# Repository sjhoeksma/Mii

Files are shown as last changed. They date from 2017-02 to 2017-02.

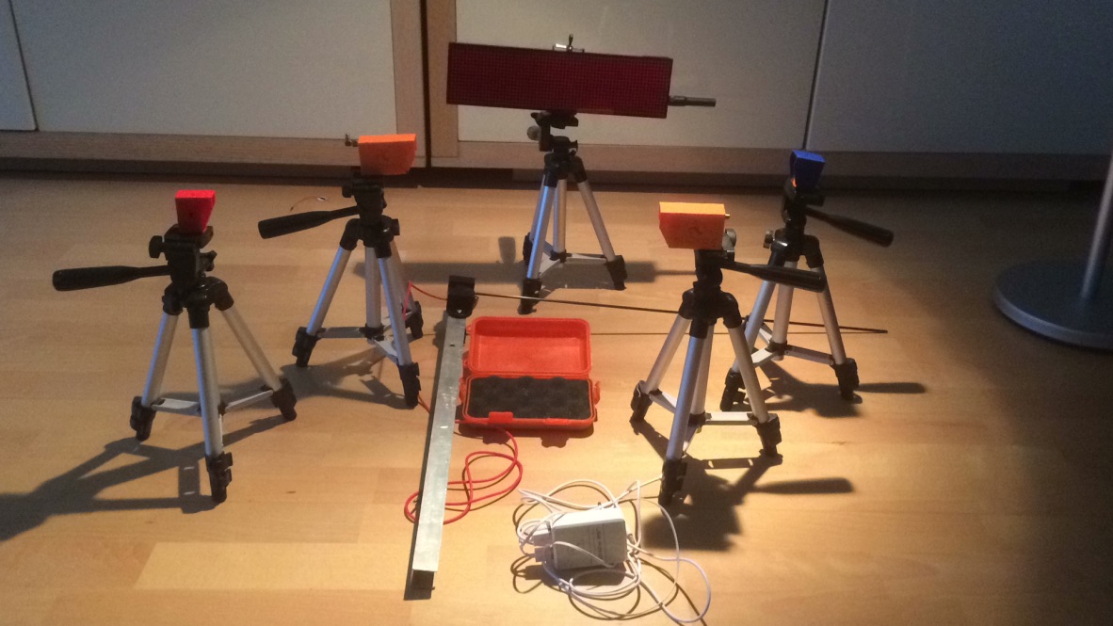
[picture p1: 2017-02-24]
img/overview.jpg

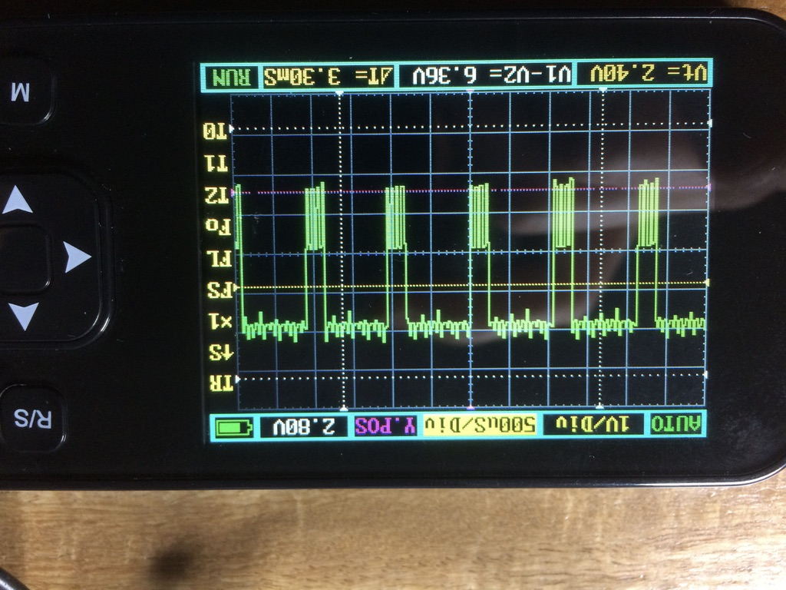
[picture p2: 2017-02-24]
img/pulsetrain.jpg

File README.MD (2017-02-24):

# Mii an Opensource Real Time, Timing solution
This solution can be used to create your own real time timing solution. It can be for example be used for mesuaring
the time needed to run a 10 meter sprint or do ski run.

We provide the hardware components, created with Eagle from CadSoft, emmbedded software written in arduino and a HTML5 app for Web & Mobile devices written with IONIC framework 1.3. For hardware components we provide the 3D models allowing you to print them your self.

## Components
1. MiiChrono and a MiiBeam make a start of finish line
2. MiiScoreboard can be used to show the time
3. MiiApp is the HMTL5 app
4. Mii3D are the 3D models for your printer in using openScad
5. Lib contains all libaries you need

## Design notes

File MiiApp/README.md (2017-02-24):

# 1. MiiApp Ionic Framework
Thanks for your interest in the **MiiApp Ionic Framework**. This framework will reduce the effort you require to build great hybrid applications.
We have combined the most common used native functions and with some great functions like dynamic load, so you can just focus on writting your code in HTML5.

## 1.1 Install Android Studio and XCode
Before you can build a native application your need to install Android Studio and XCode
1. Android: https://developer.android.com/studio/index.html
1. Apple: XCode from Appstore

## 1.2 Installing from scratch
1. Download nodejs from https://nodejs.org/en/download/ and install it
1. sudo npm install -g ionic
1. sudo npm install -g bower
1. sudo npm install -g cordova
1. sudo npm install -g gulp

Run cordova to complete the cordova installation

```
cordova
```

Install the following pacakges to install the IOS simulator on MacOS.

1. sudo npm install -g ios-sim
1. sudo npm install -g ios-deploy --unsafe-perm=true  --allow-root

## 1.3 Clone the repository
Make a clone of our repository with your GIT tool.

```
git clone https://github.com/sjhoeksma/dwp-ss.git
cd dwp-ss
```

## 1.4 Download all required packages
1. npm install
1. bower install
1. ionic state reset
1. ionic resources

## 1.5 Additional Platforms
By default we install IOS and Android would you like to add another platform just list type **ionc platform ls** and then add type **ionic platform add XXX**
 
# 2. Start your development
You have now successfully installed Ionic and our framework. You will need to configure it. Open the file [www/js/config.js](https://github.com/sjhoeksma/dwp-ss/blob/master/www/js/config.js) and set your preferences.
We support different kind of secuirty elements enabling you to make enterprise grade applications. By default all security and backend services are **disabled**.

## 2.1 Understanding the architecture

### Evergreen process of modules (remote sync)
We use a evergreen process to keep your mobile application updated to latest version. This will require you to deploy the framework towards a webserver. During the build process we create a **modules.json** file containing all available modules and there version number. For all modules you have installed we will check if there is a never version available on the webserver and then download and install it. Next time you application goes to the home state **app.home** the application will reload and you have the latest version of all modules.

## 2.2 Create your first Module

## 2.3 Build or Test your first Module
Now you have you created your module you want to test it. You should first test your app in the browser by using the following command from the root directory of your project.

```
ionic serve -c -l
```
This will start up your browser and the live reload services and dumps all message of the console.

If you are happy with you code you can build a real version and test it in an emulator like this

```
ionic emulate ios -c -l
or
ionic emulate android -c -l
```
This will start the emulator of your choice, in live reload. If you want to have a real package remove *-c -l*. 

**Warning: On android no cordova plugins are loaded when using live reload**

When you are finally happy with your result you can run in on a real device by using.

```
ionic run
```
or even build the real version

```
ionic build --production
or
ionic build [--development]
```
The prodcution build will create a compressed version of the code, without debug infomation. Therefor you should not use it for testing purposes. Development is the default behaivour. You will need to sign your app before you can deploy them to a appstore or any apple device.

## 2.4 Setup signing of application
### Android

### Apple

## 2.5 Developer documentation
The framework comes with a number of states, which you may want to overwrite of use
* **app.home** The default home screen contains a single app or a grid of apps when more installed
* **app.settings** Screen where use can changes general settings (language,theme) or module specific
* **app.store** A store where a user can add or remove a module
* **app.notifications** A webpage showing all notifications
* **app.about** Text about your app (basic info in language files)
* **app.firsttime** Text show when user starts application for fist time (basic info in language files)
* **app.whatsnew** Text shown when a new version of the application is started after download from app store (basic info in language files)

#### Pages normally not modified (except language files)
* **app.login** The login page.
* **app.logout** This state will redirect automactily back to the app.login state
* **app.webpage** Opens the webpage in iframe of in appbrowser depending on the config you specified
* **app.privacy** This page shows general information about how you should use this app if you want to protect you privacy as a end user
* **app.opensource** This page shows the opensource license and all links to the packages we have used.

* **app.newpin** This is a model view page which is shown in case an user needs to set a pin. This function can be used by enterprise who use a claim based authorization model and want to lock the user after x minutues of in activity, but don't require the user to retreive a new claim. When a pin code is set we will use this pincode to encrypt data in the app.

All the Factories,Providers and Services within the framework are document using ngDoc. We do our best to make usable documentation, but please help us making it exellent.

**Directives**
* [IonKeyPad]()
* [MenuTree]()
* [GridMenu]()

**Providers**
* [SecureStorage]()
* [LoadOnDemand]()
* [SyncQueue]()
* [FilePicker]()

**Services**
* [AppUser]()
* [IdelStateTimer]()
* [NetworkMonitor]()
* [Notifications]()

# 3. Technical information
This section explains the installation process of all packages used by the framework. You don't need to do this is you have followed the instructions at the beginning of this document

## 3.1 Codova plugins packages
Cordova plugins are automaticly to packages.json and therefor reloaded during the state reset command of ionic. If for some reason this did not happend you can add the packages yourself.
* ionic plugin add cordova-plugin-whitelist  --save
* ionic plugin add cordova-plugin-appavailability --save
* ionic plugin add cordova-plugin-camera --save
* ionic plugin add cordova-plugin-network-information --save
* ionic plugin add cordova-plugin-file --save
* ionic plugin add cordova-plugin-powermanagement --save
* ionic plugin add cordova-plugin-vibration --save
* ionic plugin add cordova-plugin-app-version --save
* ionic plugin add cordova-plugin-keychain-touch-id --save
* ionic plugin add cordova-plugin-crosswalk-webview@1.7 --save
* ionic plugin add cordova-plugin-nativeclicksound --save
* ionic plugin add cordova-plugin-badge --save
* ionic plugin add cordova-plugin-ms-adal --save
* ionic plugin add cordova-plugin-themeablebrowser --save 
* ionic plugin add phonegap-plugin-push --variable SENDER_ID=123232 --save
* ionic plugin add phonegap-plugin-contentsync --save
* ionic plugin add cordova-custom-config --save
* ionic plugin add cordova-plugin-file-transfer --save
* ionic plugin add http://github.com/don/cordova-filechooser.git --save
* ionic plugin add cordova-plugin-backbutton --save
* ionic plugin add cordova-plugin-bluetooth-serial --save

## 3.2 Javascript libraries
JavaScript libraries are also automaticly added during the ionic state reset command because they where added to bower.json.
* bower install --save angular-translate
* bower install --save angular-translate-loader-static-files
* bower install --save angular-translate-loader-partial
* bower install --save angular-cookies
* bower install --save crypto-js
* bower install --save ngCordova
* bower install --save ion-datetime-picker
* bower install --save jquery 
* bower install --save nz-tour
* bower install --save crypto-js
* bower install --save idle.js
* bower install --save Leaflet
* bower install --save adal-angular
* bower install --save https://github.com/sjhoeksma/ionic-gizmos.git
* bower install --save https://github.com/sjhoeksma/nzTour.git
* bower install --save ionic-select-control
* bower install --save localforage 
* bower install --save angular-localforage
* bower install --save https://github.com/localForage/localForage-sessionStorageWrapper.git
* bower install --save angular-formly
* bower install --save owl.carousel
* bower install --save pdfmake

## 3.3 Setting up testing with karma 
Based on the following links: [link1](http://mcgivery.com/unit-testing-ionic-app) and [link2](http://gonehybrid.com/how-to-write-automated-tests-for-your-ionic-app-part-2/) we have created some unit test. To run a test you can use the command **gulp test** from the command line.

```
npm install karma karma-jasmine jasmine-core karma-phantomjs-launcher karma-html-reporter karma-chrome-launcher karma-mocha-reporter karma-ng-html2js-preprocessor karma-html-reporter --save
bower install angular-mocks#1.5.x --save
sudo npm install -g karma-cli
sudo npm install -g phantomjs
mkdir -p tests/unit-tests
cd tests
karma init unit-tests.conf.js
```

## 3.4 Known Issues
1. When login you can be prompted to validate adfs again we trigger autheticate while user entered Valid Pin
2.

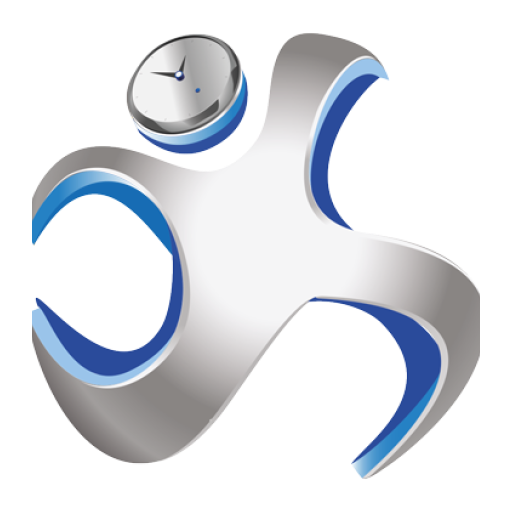
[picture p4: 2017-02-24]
MiiApp/www/modules/app.miichrono/miichrono.png

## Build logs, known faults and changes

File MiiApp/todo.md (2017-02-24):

BaasBox.com als vervanging van Backendless.com
Disable ADAL by option
+Disable login option
+Single App loaded start app directly
Secure storage without encryption
Secure storage with WebCrypto
+Secure storage remove native option
Remove bug, hardware back button on forget's go's to home
Looks like loading of scripts not yet correct. MiiChrono does not work without outloading
+Show time clock in App
+Set time of phone when time is not set
+Divider when using ranking by group
+Selection of time should be better
+Save the settings
copy user by cloning from other session
firmware sometimes empty resend request
style sheet blue is keyboard transparent
+ranking does not work with without gender (looks like we need two before it works)
+reopen time does not work, should be not visable when not connected, and only if within last received block
+focusme in ionicpopup
+add session werkt niet
+dnf can be reopend
+no differance in ranking / no group
+tijd clock in local time
send result to bluetooth printer
does auto reconnect while use bluetooth is disabeld
+Strange behavoiur on ionicpopup firstime data is not connected	
+use bleutooth of seems to block outgoing commands ?
App create pdf with report and share (https://github.com/EddyVerbruggen/SocialSharing-PhoneGap-Plugin)
Full screen for time
+Follow user list
Remove item from middle of list goes wrong
+Have option to view list bast on start nr / Seq Nr
Have option to add seqnr to user,more data like points
Have a option to sort start list base on points
upload user and data
+When deleteing 3 items ranking was off
+Change user to time in popover
+check how data/time is set, should delta be removed
+have option to add next on start to app
Just log switches, so we can set time manual
+System goes in parrallel mode ? --> Locks like display issue (increase keyboard val with 5 and moved code down)
+No difference shown for empty groups/gender
+on disconnect clear all active times
full screen on rotate of device (landscape)
+Blink red on master when no devices connected
+Support parrallel mode
+Finish van nieuwe set blijft rebooten, --> Pin SW2 van audoplug op board stond open
+reset should also send reset to device when connected
+Paralel op display geef rare text L?, moet L+ zijn
Display is reseting,  check if condensator is 47uf (done)
Pallel mode what to display what in APP, (show only finish list, with no diff and no rank)
Option to keep keyboard to enter seqeunce always on (Snele invoer van volgende start nr)
Add config option to app forcing ping code top be set active, or general option
Move apitoken and login to service to app, allow for sharing the same login 

Replace the $http function with option to use a state config, therefore we should add state to queue

3D printing
Create a click for the start gate war stokje in past
Gate met externe spring veer

Lint the javascripts

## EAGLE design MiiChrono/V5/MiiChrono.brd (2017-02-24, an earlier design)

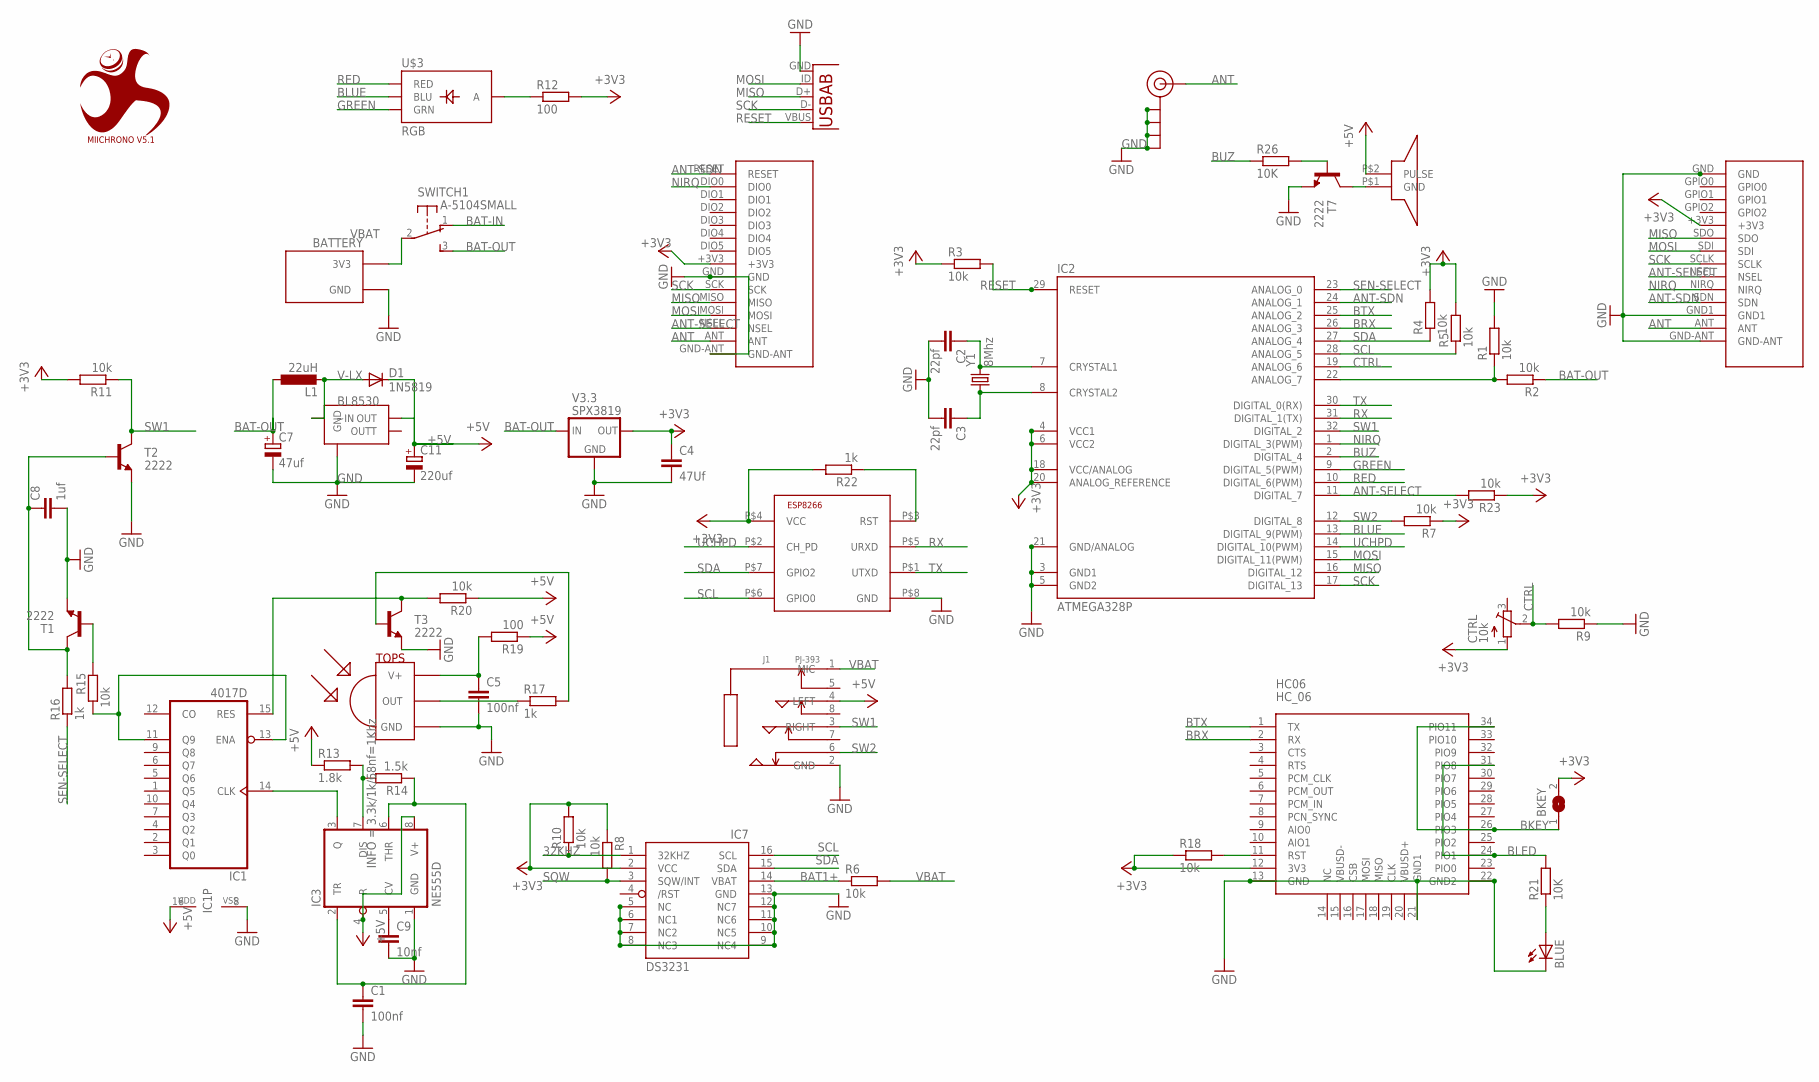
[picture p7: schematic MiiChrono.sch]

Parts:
BATTERY: GOPRO3BATTERY
BKEY: SOLDERJUMPER; SOLDERJUMPER_ARROW_NOPASTE
BL8530: BL8530; SOT89
BLUE: LEDCHIP-LED0805; CHIP-LED0805
BUZZER: BUZZER
C1, C5: 100nf; C0805
C2, C3: 22pf; C0805
C4: 47Uf; C0805
C7: 47uf; SMC_A
C8: 1uf; C0805
C9: 10nf; C0805
C11: 220uf; CT3528
CTRL: 10k; TC33X
D1: 1N5819; DO214AC
HC06: HC_06; BLUETOOTH_SMD
IC1: 4017D; SO16
IC2: ATMEGA328P; TQFP32-08
IC3: NE555D; SO08
IC7: DS3231/SO; SO16W
ISP1: USB-ABUSB_SIERK; USB_AB_MICRO_SJH
J1: PJ-393; AUDIO8P-SMD-3.5-14.5X6.1X4.0MM
J$1: SMA_EDGE; SMA-EDGE
L1: 22uH; L1812
R1, R2, R3, R4, R5, R6, R7, R8, R9, R10, R11, R15, R18, R20, R23: 10k; R0805
R12, R19: 100; R0805
R13: 1.8k; R0805
R14: 1.5k; R0805
R16, R17, R22: 1k; R0805
R21, R26: 10K; R0805
SWITCH: A-5104SMALL; A-5104-SMALL
T1, T2, T3, T7: 2222; SOT23
TOPS: TSOP4838; TSOP18XX
U$1: MIICHRONO V5.1; MIICHRONO
U$2: DRF1278F
U$3: RGB; LED-TRICOLOR-SMD
U$4: ESP8266-01; ESP-01
U$7: SI4432
V3.3: SPX3819; SOT23-5
Y1: 8Mhz; HC49UP

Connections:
32KHZ: IC7.1 (32KHZ), R10.1
+3V3: BKEY.2, C4.1, CTRL.1 (A), HC06.12 (3V3), IC2.4 (VCC1), IC2.6 (VCC2), IC2.18 (VCC/ANALOG), IC2.20 (ANALOG_REFERENCE), IC7.2 (VCC), R3.1, R4.2, R5.2, R7.1, R8.1, R10.2, R11.2, R12.2, R18.1, R22.2, R23.1, U$2.+3V3, U$4.P$4 (VCC), U$7.+3V3, V3.3.5 (OUT)
+5V: BL8530.2 (OUT), BUZZER.P$2 (PULSE), C11.+, D1.C, IC1.16 (VDD), IC3.4 (R), IC3.8 (V+), J1.4 (LEFT), R13.1, R19.1, R20.1
ANT: J$1.$P1 (SIGNAL), U$2.ANT, U$7.ANT
ANT-SDN: IC2.24 (ANALOG_1), U$2.RESET, U$7.SDN
ANT-SELECT: IC2.11 (DIGITAL_7), R23.2, U$2.NSEL, U$7.NSEL
BAT1+: IC7.14 (VBAT), R6.1
BAT-IN: SWITCH.1 (O)
BAT-OUT: C7.+, L1.1, R2.1, SWITCH.3 (S), V3.3.1 (IN), V3.3.3 (IN)
BKEY: BKEY.1, HC06.26 (PIO3), HC06.34 (PIO11)
BLED: HC06.24 (PIO1), HC06.31 (PIO8), R21.2
BLUE: IC2.13 (DIGITAL_9(PWM)), U$3.B (BLU)
BRX: HC06.2 (RX), IC2.26 (ANALOG_3)
BTX: HC06.1 (TX), IC2.25 (ANALOG_2)
BUZ: IC2.2 (DIGITAL_4), R26.1
CTRL: CTRL.2 (S), IC2.19 (ANALOG_6), R9.2
GND: BATTERY.GND, BL8530.1 (GND), BLUE.C, C1.2, C2.2, C3.2, C4.2, C5.2, C7.-, C8.2, C9.2, C11.-, HC06.13 (GND), HC06.21 (GND1), HC06.22 (GND2), IC1.8 (VSS), IC2.3 (GND1), IC2.5 (GND2), IC2.21 (GND/ANALOG), IC3.1 (GND), IC7.5 (NC), IC7.6 (NC1), IC7.7 (NC2), IC7.8 (NC3), IC7.9 (NC4), IC7.10 (NC5), IC7.11 (NC6), IC7.12 (NC7), IC7.13 (GND), ISP1.GND, J1.2 (GND), J$1.GND@0 (GND), J$1.GND@1 (GND), J$1.GND@2 (GND), J$1.GND@3 (GND), R1.2, R9.1, T1.2 (E), T2.2 (E), T3.2 (E), T7.2 (E), TOPS.GND, U$2.GND, U$2.GND-ANT, U$4.P$8 (GND), U$7.GND, U$7.GND1, U$7.GND-ANT, V3.3.2 (GND)
GREEN: IC2.9 (DIGITAL_5(PWM)), U$3.G (GRN)
MISO: IC2.16 (DIGITAL_12), ISP1.D+, U$2.MISO, U$7.SDO
MOSI: IC2.15 (DIGITAL_11(PWM)), ISP1.ID (USBID), U$2.MOSI, U$7.SDI
unnamed: R17.2, T3.1 (B)
unnamed: C9.1, IC3.5 (CV)
unnamed: HC06.11 (RST), R18.2
unnamed: C8.1, R16.2, T1.3 (C), T2.1 (B)
unnamed: IC1.11 (Q9), IC1.13 (ENA), R15.1
unnamed: R22.1, U$4.P$3 (RST)
unnamed: C3.1, IC2.8 (CRYSTAL2), Y1.1
unnamed: C2.1, IC2.7 (CRYSTAL1), Y1.2
unnamed: R15.2, T1.1 (B)
unnamed: R12.1, U$3.A
unnamed: C1.1, IC3.2 (TR), IC3.6 (THR), R14.1
unnamed: BLUE.A, R21.1
unnamed: IC1.14 (CLK), IC3.3 (Q)
unnamed: IC3.7 (DIS), R13.2, R14.2
unnamed: R17.1, TOPS.OUT
unnamed: C5.1, R19.2, TOPS.VCC (V+)
unnamed: IC1.15 (RES), R20.2, T3.3 (C)
unnamed: IC2.22 (ANALOG_7), R1.1, R2.2
unnamed: R26.2, T7.1 (B)
unnamed: BUZZER.P$1 (GND), T7.3 (C)
NIRQ: IC2.1 (DIGITAL_3(PWM)), U$2.DIO0, U$7.NIRQ
RED: IC2.10 (DIGITAL_6(PWM)), U$3.R (RED)
RESET: IC2.29 (RESET), ISP1.VBUS, R3.2
RX: IC2.31 (DIGITAL_1(TX)), U$4.P$5 (URXD)
SCK: IC2.17 (DIGITAL_13), ISP1.D-, U$2.SCK, U$7.SCLK
SCL: IC2.28 (ANALOG_5), IC7.16 (SCL), R5.1, U$4.P$6 (GPIO0)
SDA: IC2.27 (ANALOG_4), IC7.15 (SDA), R4.1, U$4.P$7 (GPIO2)
SEN-SELECT: IC2.23 (ANALOG_0), R16.1
SQW: IC7.3 (SQW/INT), R8.2
SW1: IC2.32 (DIGITAL_2), J1.3 (RIGHT), R11.1, T2.3 (C)
SW2: IC2.12 (DIGITAL_8), J1.6, R7.2
TX: IC2.30 (DIGITAL_0(RX)), U$4.P$1 (UTXD)
UCHPD: IC2.14 (DIGITAL_10(PWM)), U$4.P$2 (CH_PD)
V-LX: BL8530.3 (~IN), D1.A, L1.2
VBAT: BATTERY.3V3, J1.1 (MIC), R6.2, SWITCH.2

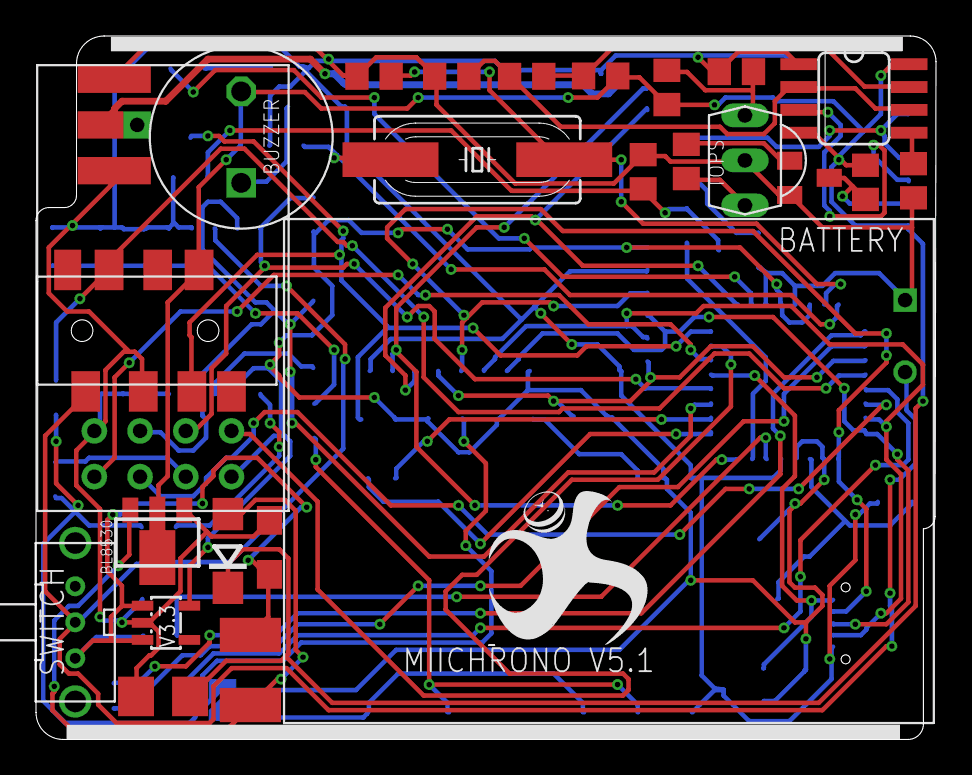
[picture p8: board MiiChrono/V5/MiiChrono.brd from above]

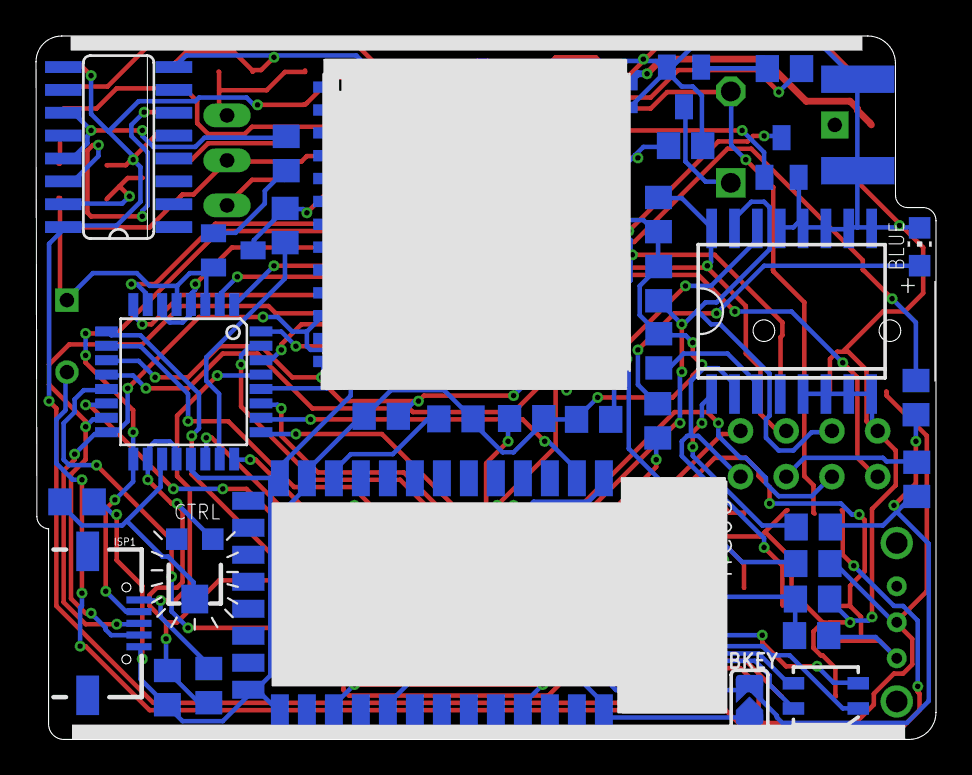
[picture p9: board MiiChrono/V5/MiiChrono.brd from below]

Board: 2 copper layers, 50.0 x 39.1 mm, 62 parts (35 on the bottom side), 54 nets.

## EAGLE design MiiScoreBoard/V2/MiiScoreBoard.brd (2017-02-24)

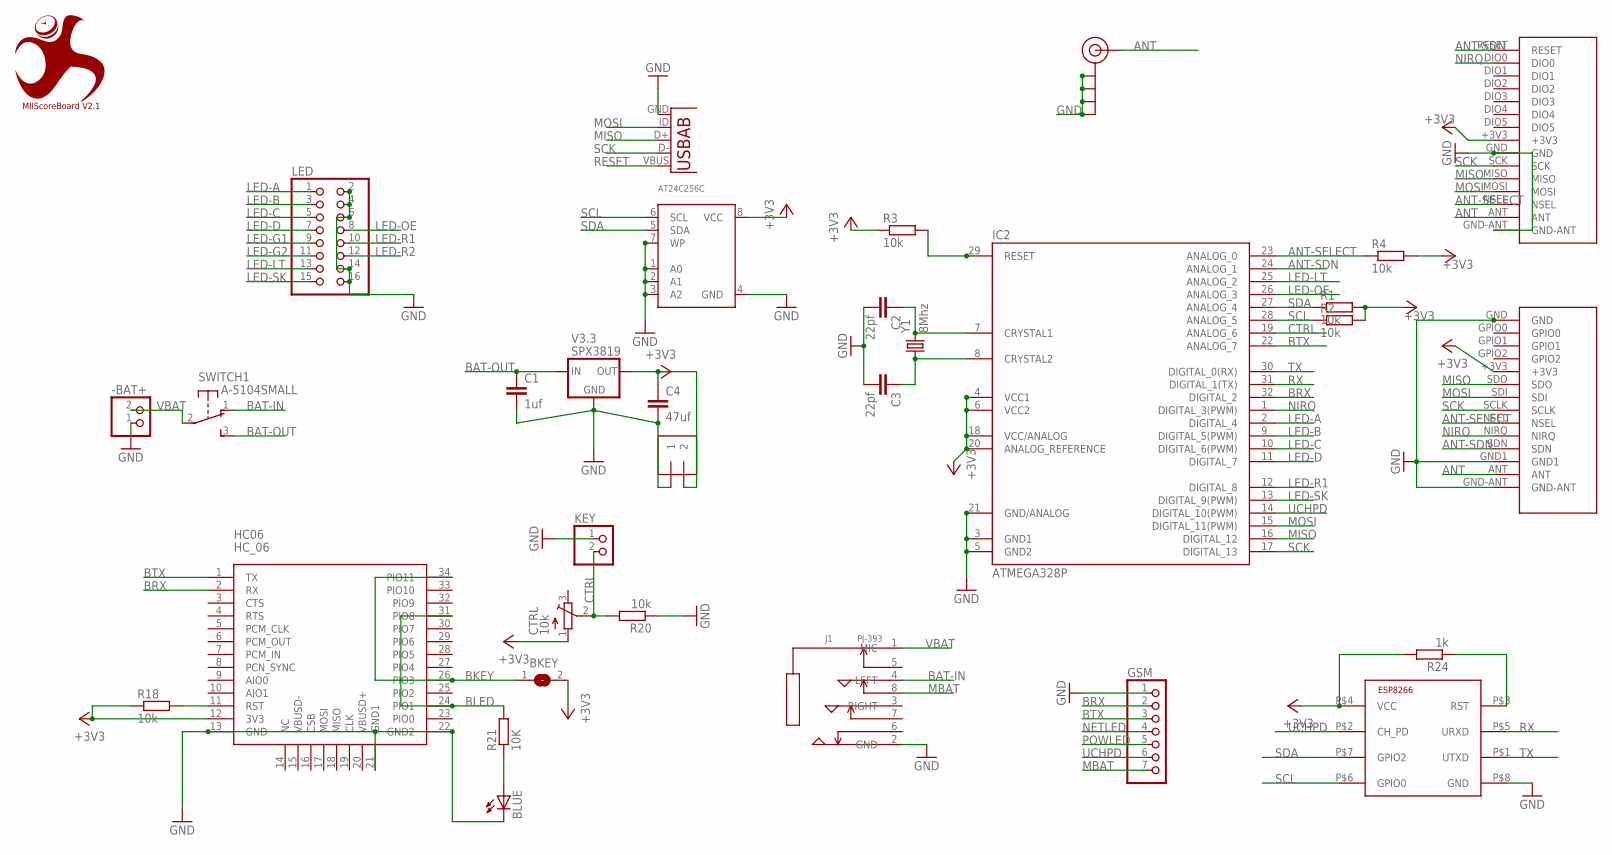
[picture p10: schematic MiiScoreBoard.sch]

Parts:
-BAT+: JST_2PIN-THM; JST-PH-2-THM
-LED+: -BAT+; 1X2-3.5MM
AT24C256C: EEPROM_I2C_SOIC8_GENERIC; SOIC8_150MIL
BKEY: SOLDERJUMPER; SOLDERJUMPER_ARROW_NOPASTE
BLUE: LEDCHIP-LED0805; CHIP-LED0805
C1: 1uf; C0805
C2, C3: 22pf; C0805
C4: 47uf; C0805
CTRL: 10k; TC33X
GSM: PINHD-1X07_2.54; 1X07
HC06: HC_06; BLUETOOTH_SMD
IC2: ATMEGA328P; TQFP32-08
ISP1: USB-ABUSB_SIERK; USB_AB_MICRO_SJH
J1: PJ-393; AUDIO8P-SMD-3.5-14.5X6.1X4.0MM
J$1: SMA_EDGE; SMA-EDGE
KEY: PINHD-1X02_2.54-90°; 1X02/90
LED: PINHD-2X08_2.54; 2X08
R1, R2, R3, R4, R18, R20: 10k; R0805
R21: 10K; R0805
R24: 1k; R0805
SWITCH: A-5104SMALL; A-5104-SMALL
U$1: MIIScoreBoard V2.1; MIICHRONO
U$2: DRF1278F
U$6: ESP8266-01; ESP-01
U$7: SI4432
V3.3: SPX3819; SOT23-5
Y1: 8Mhz; HC49UP

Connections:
+3V3: -LED+.2, AT24C256C.8 (VCC), BKEY.2, C4.1, CTRL.1 (A), HC06.12 (3V3), IC2.4 (VCC1), IC2.6 (VCC2), IC2.18 (VCC/ANALOG), IC2.20 (ANALOG_REFERENCE), R1.2, R2.2, R3.1, R4.2, R18.1, R24.2, U$2.+3V3, U$6.P$4 (VCC), U$7.+3V3, V3.3.5 (OUT)
ANT: J$1.$P1 (SIGNAL), U$2.ANT, U$7.ANT
ANT-SDN: IC2.24 (ANALOG_1), U$2.RESET, U$7.SDN
ANT-SELECT: IC2.23 (ANALOG_0), R4.1, U$2.NSEL, U$7.NSEL
BAT-IN: J1.4 (LEFT), SWITCH.1 (O)
BAT-OUT: C1.1, SWITCH.3 (S), V3.3.1 (IN), V3.3.3 (IN)
BKEY: BKEY.1, HC06.26 (PIO3), HC06.34 (PIO11)
BLED: HC06.24 (PIO1), HC06.31 (PIO8), R21.2
BRX: GSM.2, HC06.2 (RX), IC2.32 (DIGITAL_2)
BTX: GSM.3, HC06.1 (TX), IC2.22 (ANALOG_7)
CTRL: CTRL.2 (S), IC2.19 (ANALOG_6), KEY.2, R20.2
GND: -BAT+.1 (2), -LED+.1, AT24C256C.1 (A0), AT24C256C.2 (A1), AT24C256C.3 (A2), AT24C256C.4 (GND), AT24C256C.7 (WP), BLUE.C, C1.2, C2.2, C3.2, C4.2, GSM.1, HC06.13 (GND), HC06.21 (GND1), HC06.22 (GND2), IC2.3 (GND1), IC2.5 (GND2), IC2.21 (GND/ANALOG), ISP1.GND, J1.2 (GND), J$1.GND@0 (GND), J$1.GND@1 (GND), J$1.GND@2 (GND), J$1.GND@3 (GND), KEY.1, LED.2, LED.4, LED.6, LED.14, LED.16, R20.1, U$2.GND, U$2.GND-ANT, U$6.P$8 (GND), U$7.GND, U$7.GND1, U$7.GND-ANT, V3.3.2 (GND)
LED-A: IC2.2 (DIGITAL_4), LED.1
LED-B: IC2.9 (DIGITAL_5(PWM)), LED.3
LED-C: IC2.10 (DIGITAL_6(PWM)), LED.5
LED-D: IC2.11 (DIGITAL_7), LED.7
LED-G1: LED.9
LED-G2: LED.11
LED-LT: IC2.25 (ANALOG_2), LED.13
LED-OE: IC2.26 (ANALOG_3), LED.8
LED-R1: IC2.12 (DIGITAL_8), LED.10
LED-R2: LED.12
LED-SK: IC2.13 (DIGITAL_9(PWM)), LED.15
MBAT: GSM.7, J1.8
MISO: IC2.16 (DIGITAL_12), ISP1.D+, U$2.MISO, U$7.SDO
MOSI: IC2.15 (DIGITAL_11(PWM)), ISP1.ID (USBID), U$2.MOSI, U$7.SDI
unnamed: HC06.11 (RST), R18.2
unnamed: C3.1, IC2.8 (CRYSTAL2), Y1.1
unnamed: C2.1, IC2.7 (CRYSTAL1), Y1.2
unnamed: R24.1, U$6.P$3 (RST)
unnamed: BLUE.A, R21.1
NETLED: GSM.4
NIRQ: IC2.1 (DIGITAL_3(PWM)), U$2.DIO0, U$7.NIRQ
POWLED: GSM.5
RESET: IC2.29 (RESET), ISP1.VBUS, R3.2
RX: IC2.31 (DIGITAL_1(TX)), U$6.P$5 (URXD)
SCK: IC2.17 (DIGITAL_13), ISP1.D-, U$2.SCK, U$7.SCLK
SCL: AT24C256C.6 (SCL), IC2.28 (ANALOG_5), R2.1, U$6.P$6 (GPIO0)
SDA: AT24C256C.5 (SDA), IC2.27 (ANALOG_4), R1.1, U$6.P$7 (GPIO2)
TX: IC2.30 (DIGITAL_0(RX)), U$6.P$1 (UTXD)
UCHPD: GSM.6, IC2.14 (DIGITAL_10(PWM)), U$6.P$2 (CH_PD)
VBAT: -BAT+.2 (1), J1.1 (MIC), SWITCH.2

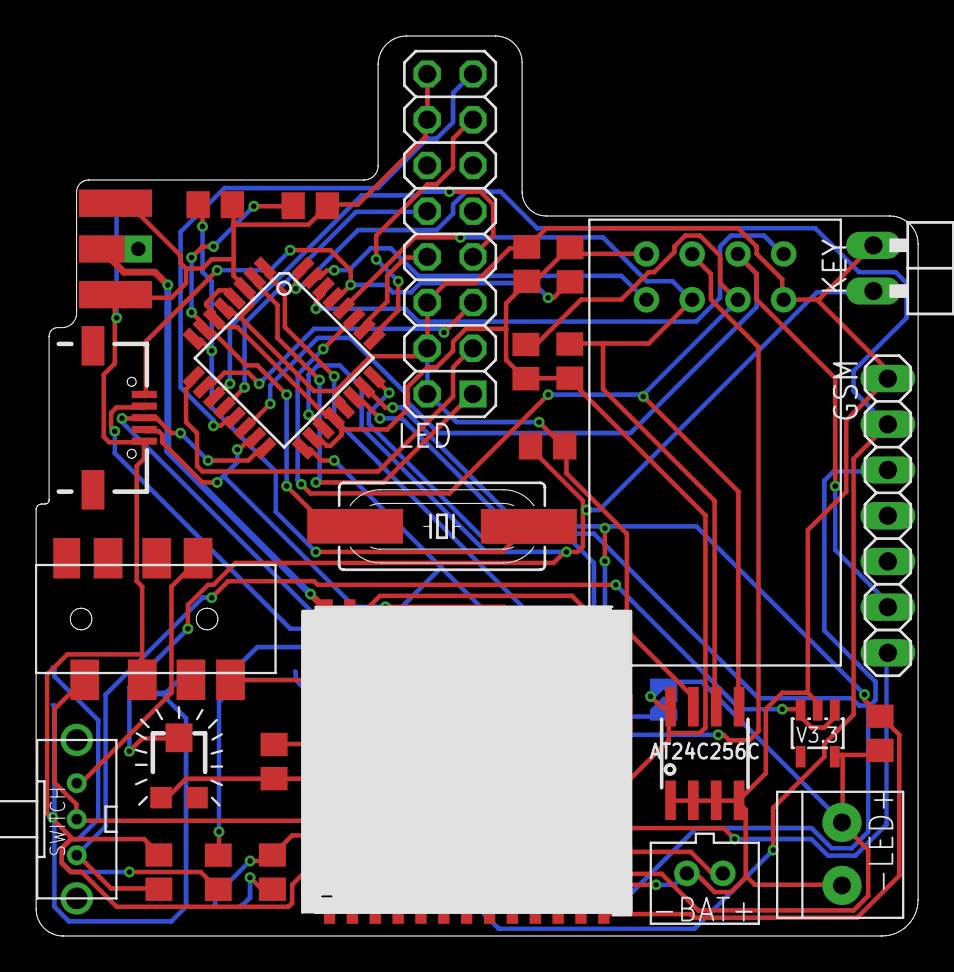
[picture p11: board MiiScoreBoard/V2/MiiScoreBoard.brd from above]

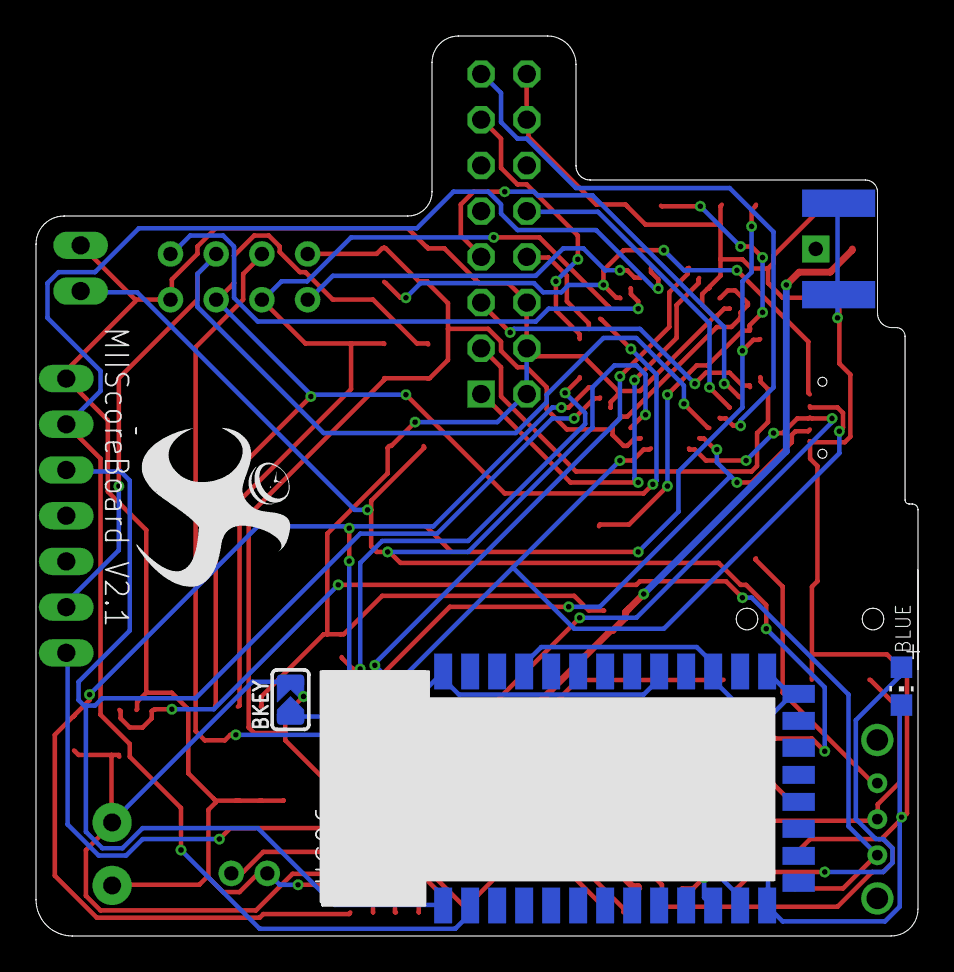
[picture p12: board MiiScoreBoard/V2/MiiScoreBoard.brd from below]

Board: 2 copper layers, 49.0 x 50.0 mm, 33 parts (4 on the bottom side), 37 nets.

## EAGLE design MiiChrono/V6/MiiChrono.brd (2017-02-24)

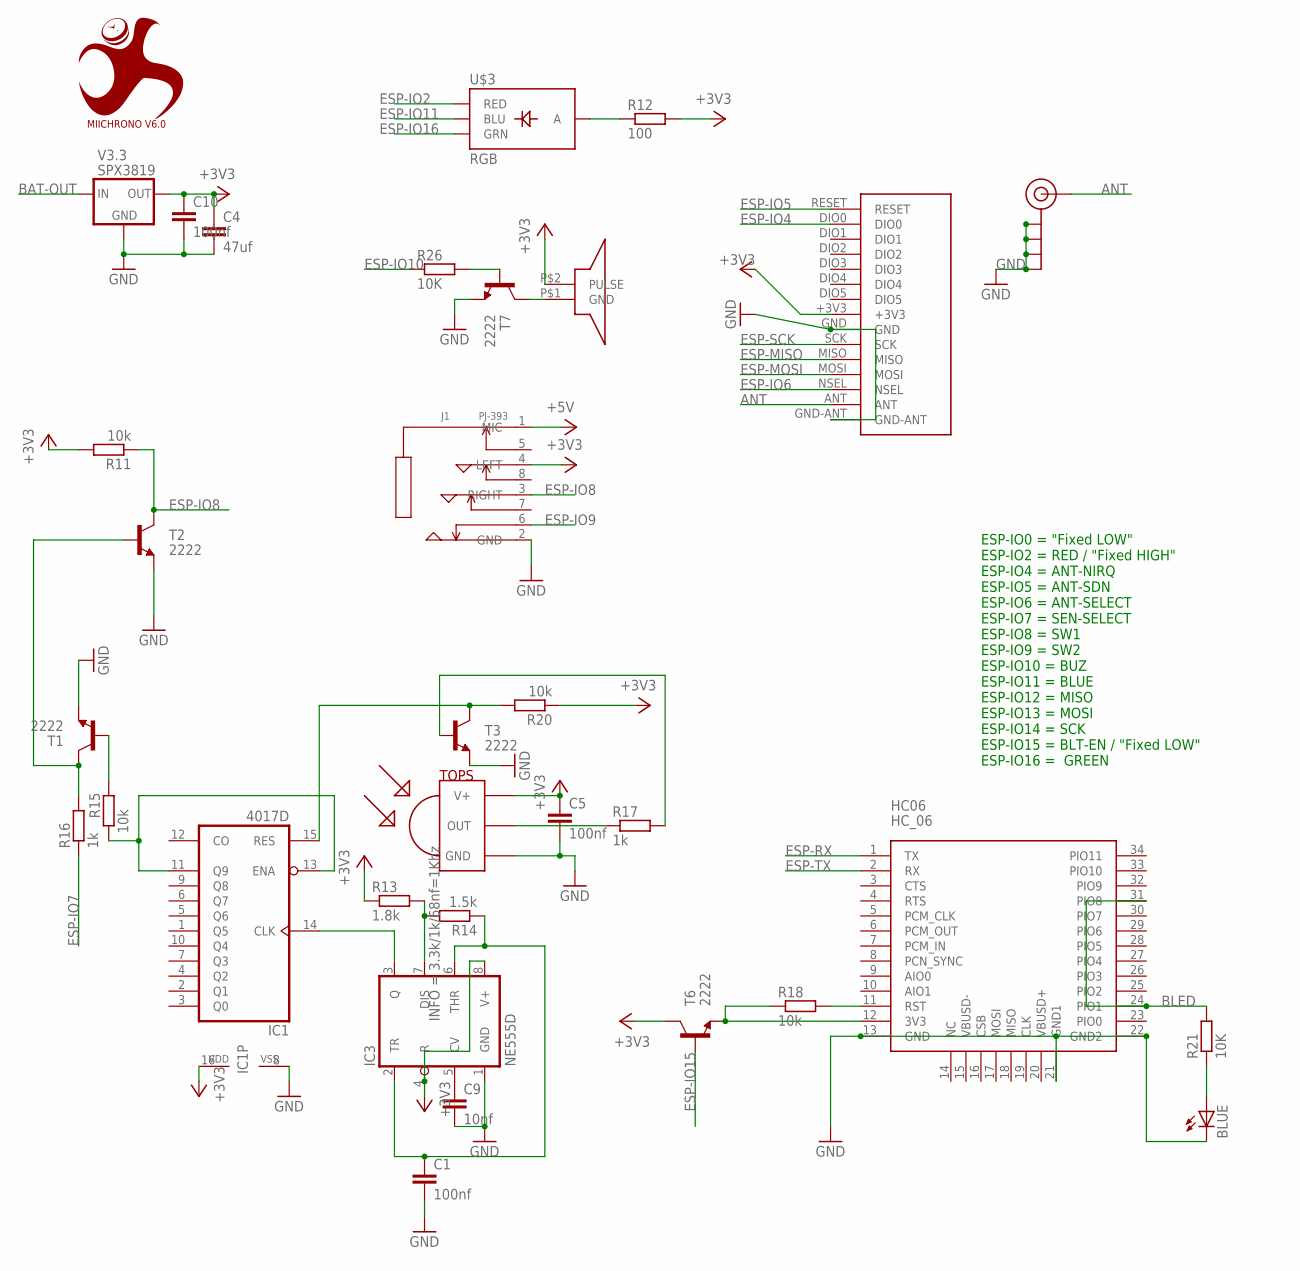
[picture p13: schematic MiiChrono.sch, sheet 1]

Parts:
BLUE: LEDCHIP-LED0805; CHIP-LED0805
BUZZER: BUZZER
C1, C5, C10: 100nf; C0805
C4: 47uf; C0805
C9: 10nf; C0805
HC06: HC_06; BLUETOOTH_SMD
IC1: 4017D; SO16
IC3: NE555D; SO08
J1: PJ-393; AUDIO8P-SMD-3.5-14.5X6.1X4.0MM
J$1: SMA_EDGE; SMA-EDGE
R11, R15, R18, R20: 10k; R0805
R12: 100; R0805
R13: 1.8k; R0805
R14: 1.5k; R0805
R16, R17: 1k; R0805
R21, R26: 10K; R0805
T1, T2, T3, T6, T7: 2222; SOT23
TOPS: TSOP4838; TSOP18XX
U$1: MIICHRONO V6.0; MIICHRONO
U$2: DRF1278F
U$3: RGB; LED-TRICOLOR-SMD
V3.3: SPX3819; SOT23-5

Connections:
+3V3: BUZZER.P$2 (PULSE), C4.1, C5.1, C10.1, IC1.16 (VDD), IC3.4 (R), IC3.8 (V+), J1.4 (LEFT), R11.2, R12.2, R13.1, R20.1, T6.3 (C), TOPS.VCC (V+), U$2.+3V3, V3.3.5 (OUT)
+5V: J1.1 (MIC); also elsewhere on the board
ANT: J$1.$P1 (SIGNAL), U$2.ANT
BAT-OUT: V3.3.1 (IN), V3.3.3 (IN); also elsewhere on the board
BLED: HC06.24 (PIO1), HC06.31 (PIO8), R21.2
ESP-IO2: U$3.R (RED); also elsewhere on the board
ESP-IO4: U$2.DIO0; also elsewhere on the board
ESP-IO5: U$2.RESET; also elsewhere on the board
ESP-IO6: U$2.NSEL; also elsewhere on the board
ESP-IO7: R16.1; also elsewhere on the board
ESP-IO8: J1.3 (RIGHT), R11.1, T2.3 (C); also elsewhere on the board
ESP-IO9: J1.6; also elsewhere on the board
ESP-IO10: R26.1; also elsewhere on the board
ESP-IO11: U$3.B (BLU); also elsewhere on the board
ESP-IO15: T6.1 (B); also elsewhere on the board
ESP-IO16: U$3.G (GRN); also elsewhere on the board
ESP-MISO: U$2.MISO; also elsewhere on the board
ESP-MOSI: U$2.MOSI; also elsewhere on the board
ESP-RX: HC06.1 (TX); also elsewhere on the board
ESP-SCK: U$2.SCK; also elsewhere on the board
ESP-TX: HC06.2 (RX); also elsewhere on the board
GND: BLUE.C, C1.2, C4.2, C5.2, C9.2, C10.2, HC06.13 (GND), HC06.21 (GND1), HC06.22 (GND2), IC1.8 (VSS), IC3.1 (GND), J1.2 (GND), J$1.GND@0 (GND), J$1.GND@1 (GND), J$1.GND@2 (GND), J$1.GND@3 (GND), T1.2 (E), T2.2 (E), T3.2 (E), T7.2 (E), TOPS.GND, U$2.GND, U$2.GND-ANT, V3.3.2 (GND); also elsewhere on the board
unnamed: R17.2, T3.1 (B)
unnamed: C9.1, IC3.5 (CV)
unnamed: R16.2, T1.3 (C), T2.1 (B)
unnamed: IC1.11 (Q9), IC1.13 (ENA), R15.1
unnamed: HC06.12 (3V3), R18.1, T6.2 (E)
unnamed: R15.2, T1.1 (B)
unnamed: R12.1, U$3.A
unnamed: C1.1, IC3.2 (TR), IC3.6 (THR), R14.1
unnamed: HC06.11 (RST), R18.2
unnamed: IC1.14 (CLK), IC3.3 (Q)
unnamed: IC3.7 (DIS), R13.2, R14.2
unnamed: R17.1, TOPS.OUT
unnamed: BLUE.A, R21.1
unnamed: IC1.15 (RES), R20.2, T3.3 (C)
unnamed: R26.2, T7.1 (B)
unnamed: BUZZER.P$1 (GND), T7.3 (C)

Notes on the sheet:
ESP-IO0 = "Fixed LOW" ESP-IO2 = RED / "Fixed HIGH" ESP-IO4 = ANT-NIRQ ESP-IO5 = ANT-SDN ESP-IO6 = ANT-SELECT ESP-IO7 = SEN-SELECT ESP-IO8 = SW1 ESP-IO9 = SW2 ESP-IO10 = BUZ ESP-IO11 = BLUE ESP-IO12 = MISO ESP-IO13 = MOSI ESP-IO14 = SCK ESP-IO15 = BLT-EN / "Fixed LOW" ESP-IO16 = GREEN

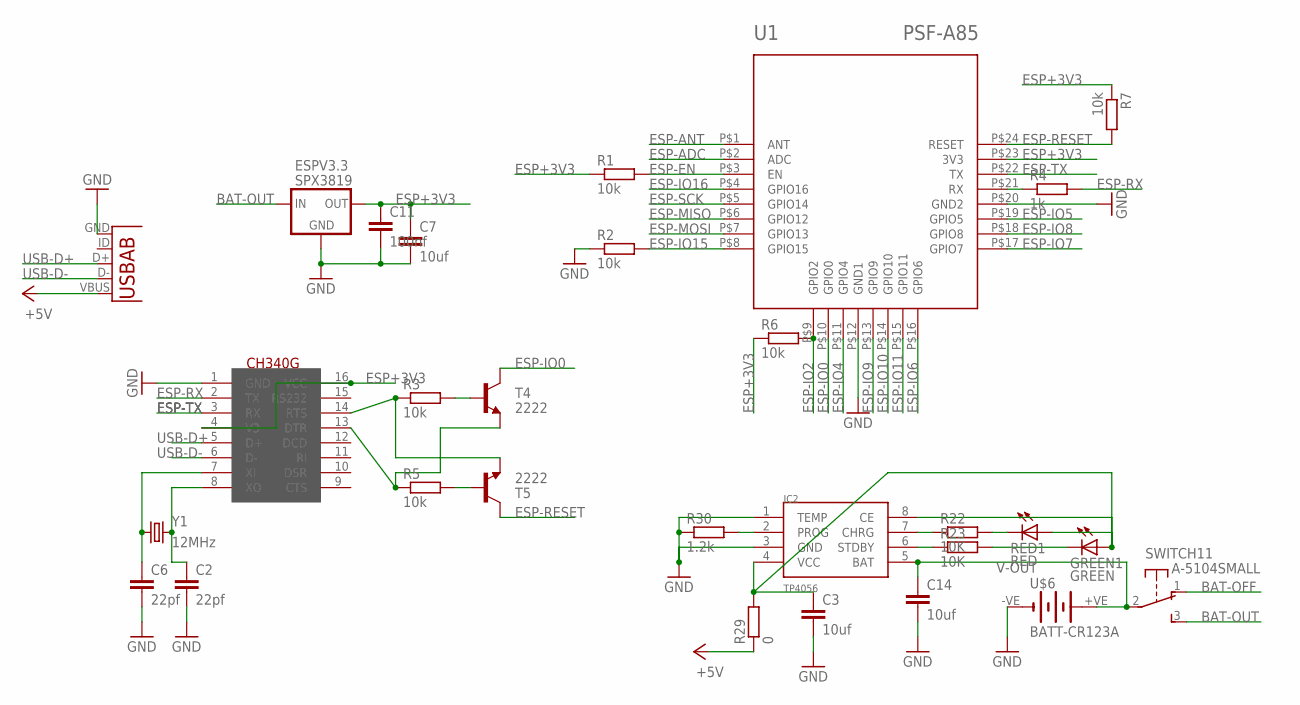
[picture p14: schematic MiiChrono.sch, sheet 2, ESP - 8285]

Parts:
C2, C6: 22pf; C0805
C3, C7, C14: 10uf; C0805
C11: 100nf; C0805
ESPV3.3: SPX3819; SOT23-5
GREEN1: GREEN; CHIP-LED0805
IC2: TP4056; SOP-8
ISP2: USB-ABUSB_SIERK; USB_AB_MICRO_SJH
R1, R2, R3, R5, R6, R7: 10k; R0805
R4: 1k; R0805
R22, R23: 10K; R0805
R29: 0; R0805
R30: 1.2k; R0805
RED1: RED; CHIP-LED0805
SWITCH1: A-5104SMALL; A-5104-SMALL
T4, T5: 2222; SOT23
U1: PSF-A85
U$5: CH340G; SOIC16
U$6: BATT-CR123A; KEYSTONE-2/3A
Y1: 12MHz; CRYSTAL-SMD-5X3

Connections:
+5V: ISP2.VBUS, R29.1; also elsewhere on the board
BAT-OFF: SWITCH1.1 (O)
BAT-OUT: ESPV3.3.1 (IN), ESPV3.3.3 (IN), SWITCH1.3 (S); also elsewhere on the board
ESP+3V3: C7.1, C11.1, ESPV3.3.5 (OUT), R1.1, R6.1, R7.1, U1.P$23 (3V3), U$5.4 (V3), U$5.16 (VCC)
ESP-ADC: U1.P$2 (ADC)
ESP-ANT: U1.P$1 (ANT)
ESP-EN: R1.2, U1.P$3 (EN)
ESP-IO0: T4.3 (C), U1.P$10 (GPIO0)
ESP-IO2: R6.2, U1.P$9 (GPIO2); also elsewhere on the board
ESP-IO4: U1.P$11 (GPIO4); also elsewhere on the board
ESP-IO5: U1.P$19 (GPIO5); also elsewhere on the board
ESP-IO6: U1.P$16 (GPIO6); also elsewhere on the board
ESP-IO7: U1.P$17 (GPIO7); also elsewhere on the board
ESP-IO8: U1.P$18 (GPIO8); also elsewhere on the board
ESP-IO9: U1.P$13 (GPIO9); also elsewhere on the board
ESP-IO10: U1.P$14 (GPIO10); also elsewhere on the board
ESP-IO11: U1.P$15 (GPIO11); also elsewhere on the board
ESP-IO15: R2.2, U1.P$8 (GPIO15); also elsewhere on the board
ESP-IO16: U1.P$4 (GPIO16); also elsewhere on the board
ESP-MISO: U1.P$6 (GPIO12); also elsewhere on the board
ESP-MOSI: U1.P$7 (GPIO13); also elsewhere on the board
ESP-RESET: R7.2, T5.3 (C), U1.P$24 (RESET)
ESP-RX: R4.2, U$5.2 (TX); also elsewhere on the board
ESP-SCK: U1.P$5 (GPIO14); also elsewhere on the board
ESP-TX: U1.P$22 (TX), U$5.3 (RX); also elsewhere on the board
GND: C2.2, C3.2, C6.2, C7.2, C11.2, C14.2, ESPV3.3.2 (GND), IC2.1 (TEMP), IC2.3 (GND), ISP2.GND, R2.1, R30.1, U1.P$12 (GND1), U1.P$20 (GND2), U$5.1 (GND), U$6.-VE (-); also elsewhere on the board
unnamed: C6.1, U$5.7 (XI), Y1.1
unnamed: C2.1, U$5.8 (XO), Y1.3 (2)
unnamed: R3.1, T5.2 (E), U$5.14 (RTS)
unnamed: R5.1, T4.2 (E), U$5.13 (DTR)
unnamed: R5.2, T5.1 (B)
unnamed: R3.2, T4.1 (B)
unnamed: R4.1, U1.P$21 (RX)
unnamed: GREEN1.C, R23.2
unnamed: R22.2, RED1.C
unnamed: IC2.7 (CHRG), R22.1
unnamed: IC2.6 (STDBY), R23.1
unnamed: IC2.2 (PROG), R30.2
USB-D+: ISP2.D+, U$5.5 (D+)
USB-D-: ISP2.D-, U$5.6 (D-)
V-IN: C3.1, GREEN1.A, IC2.4 (VCC), IC2.8 (CE), R29.2, RED1.A
V-OUT: C14.1, IC2.5 (BAT), SWITCH1.2, U$6.+VE (+)

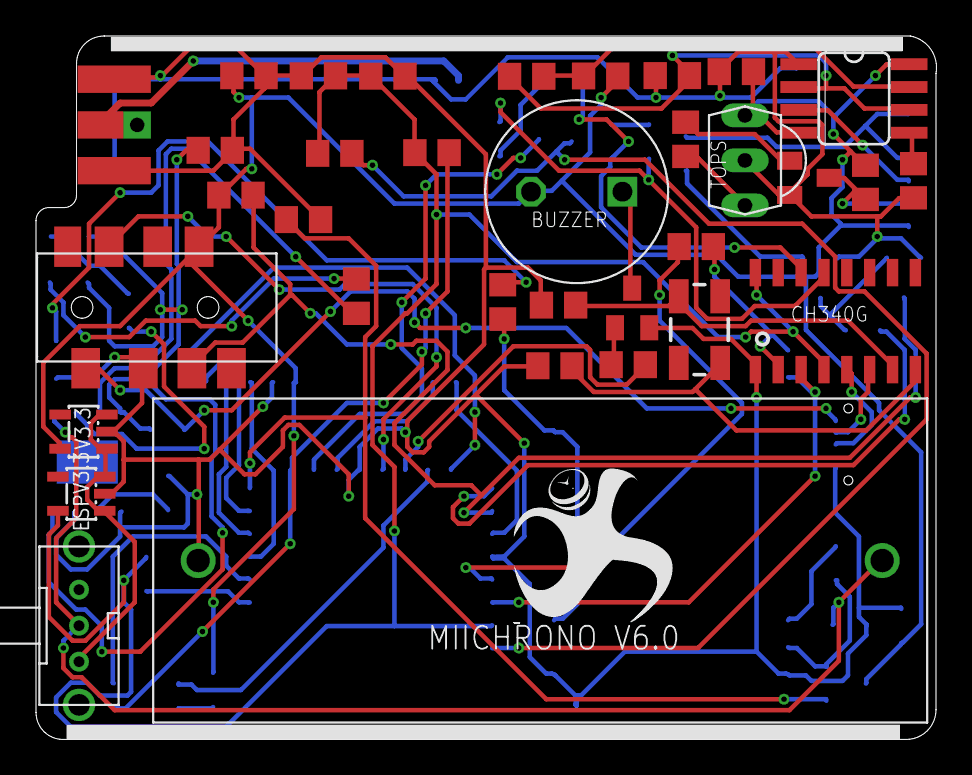
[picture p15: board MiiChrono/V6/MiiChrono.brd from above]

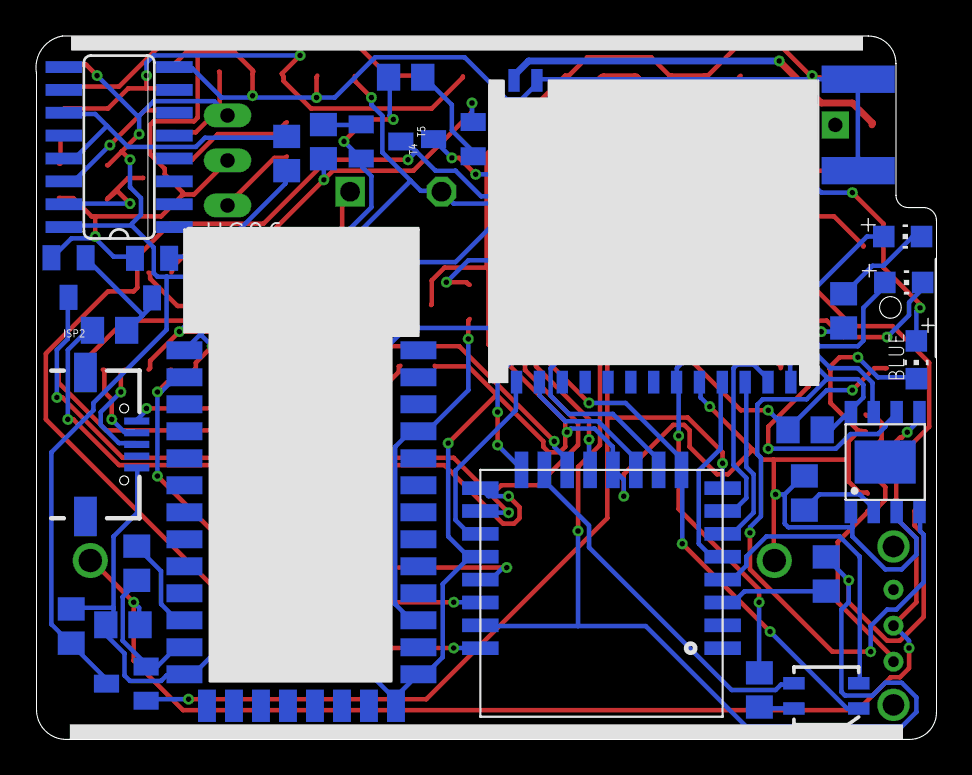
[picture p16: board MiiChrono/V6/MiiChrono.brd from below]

Board: 2 copper layers, 50.0 x 39.1 mm, 62 parts (27 on the bottom side), 58 nets.

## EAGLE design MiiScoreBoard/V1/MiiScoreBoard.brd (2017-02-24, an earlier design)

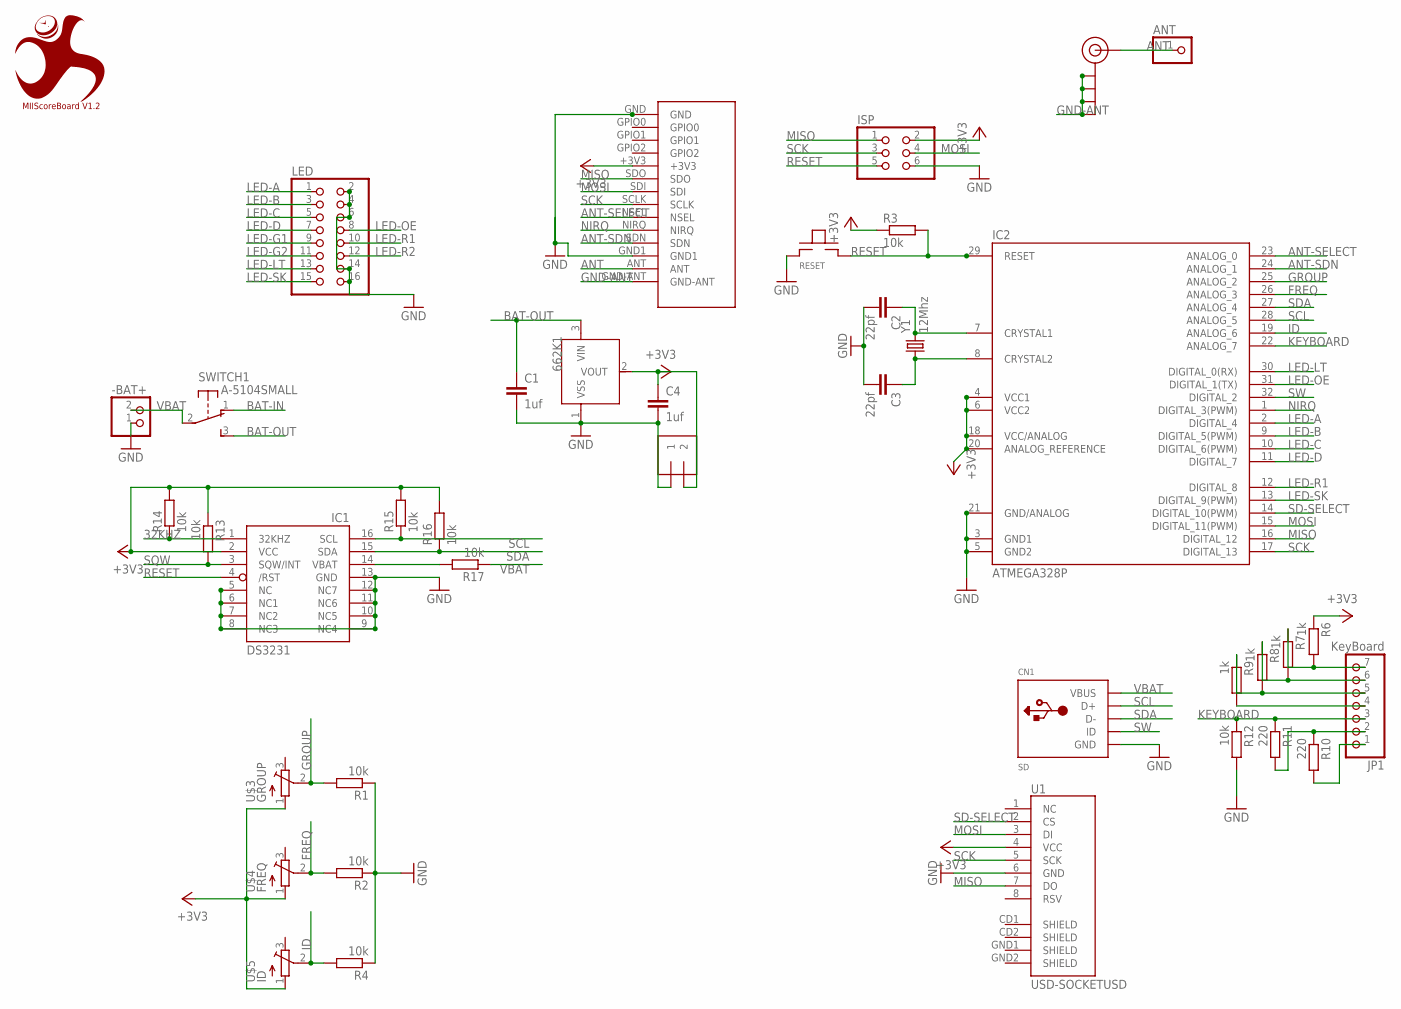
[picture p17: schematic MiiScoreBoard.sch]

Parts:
662K1: XC6206; SOT23
+LED-: -BAT+; 1X2-3.5MM
-BAT+: JST_2PIN-THM; JST-PH-2-THM
ANT: PINHD-1X01_2.00; 1X01M
C1, C4: 1uf; C0805
C2, C3: 22pf; C0805
CN1: SD; USB-MINIB
IC1: DS3231/SO; SO16W
IC2: ATMEGA328P; TQFP32-08
ISP: PINHD-2X03_2.00; 2X03M
J$1: SMA_EDGE; SMA-EDGE
JP1: KeyBoard; 1X07
LED: PINHD-2X08_2.54; 2X08
R1, R2, R3, R4, R12, R13, R14, R15, R16, R17: 10k; R0805
R6, R7, R8, R9: 1k; R0805
R10, R11: 220; R0805
RESET: TACT; TACT-TS-1289
SWITCH: A-5104SMALL; A-5104-SMALL
U1: USD-SOCKETUSD; USD-SOCKET-PP
U$1: MIIScoreBoard V1.2; MIICHRONO
U$3: GROUP; TC33X
U$4: FREQ; TC33X
U$5: ID; TC33X
U$7: SI4432
Y1: 12Mhz; HC49UP

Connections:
32KHZ: IC1.1 (32KHZ), R14.1
+3V3: 662K1.2 (VOUT), +LED-.2, C4.1, IC1.2 (VCC), IC2.4 (VCC1), IC2.6 (VCC2), IC2.18 (VCC/ANALOG), IC2.20 (ANALOG_REFERENCE), ISP.2, R3.1, R6.1, R13.1, R14.2, R15.2, R16.2, U1.4 (VCC), U$3.1 (A), U$4.1 (A), U$5.1 (A), U$7.+3V3
ANT: ANT.1, J$1.SIG (SIGNAL), U$7.ANT
ANT-SDN: IC2.24 (ANALOG_1), U$7.SDN
ANT-SELECT: IC2.23 (ANALOG_0), U$7.NSEL
BAT-IN: SWITCH.1 (O)
BAT-OUT: 662K1.3 (VIN), C1.1, SWITCH.3 (S)
FREQ: IC2.26 (ANALOG_3), R2.2, U$4.2 (S)
GND: 662K1.1 (VSS), +LED-.1, -BAT+.1 (2), C1.2, C2.2, C3.2, C4.2, CN1.GND, IC1.5 (NC), IC1.6 (NC1), IC1.7 (NC2), IC1.8 (NC3), IC1.9 (NC4), IC1.10 (NC5), IC1.11 (NC6), IC1.12 (NC7), IC1.13 (GND), IC2.3 (GND1), IC2.5 (GND2), IC2.21 (GND/ANALOG), ISP.6, LED.2, LED.4, LED.6, LED.14, LED.16, R1.1, R2.1, R4.1, R12.2, RESET.TOP-1, U1.6 (GND), U$7.GND, U$7.GND1
GND-ANT: J$1.GND@0 (GND), J$1.GND@1 (GND), J$1.GND@2 (GND), J$1.GND@3 (GND), U$7.GND-ANT
GROUP: IC2.25 (ANALOG_2), R1.2, U$3.2 (S)
ID: IC2.19 (ANALOG_6), R4.2, U$5.2 (S)
KEYBOARD: IC2.22 (ANALOG_7), JP1.3, R11.1, R12.1
LED-A: IC2.2 (DIGITAL_4), LED.1
LED-B: IC2.9 (DIGITAL_5(PWM)), LED.3
LED-C: IC2.10 (DIGITAL_6(PWM)), LED.5
LED-D: IC2.11 (DIGITAL_7), LED.7
LED-G1: LED.9
LED-G2: LED.11
LED-LT: IC2.30 (DIGITAL_0(RX)), LED.13
LED-OE: IC2.31 (DIGITAL_1(TX)), LED.8
LED-R1: IC2.12 (DIGITAL_8), LED.10
LED-R2: LED.12
LED-SK: IC2.13 (DIGITAL_9(PWM)), LED.15
MISO: IC2.16 (DIGITAL_12), ISP.1, U1.7 (DO), U$7.SDO
MOSI: IC2.15 (DIGITAL_11(PWM)), ISP.4, U1.3 (DI), U$7.SDI
unnamed: JP1.4, R9.2
unnamed: JP1.7, R6.2, R7.1
unnamed: JP1.6, R7.2, R8.1
unnamed: JP1.5, R8.2, R9.1
unnamed: JP1.1, R10.2
unnamed: C3.1, IC2.8 (CRYSTAL2), Y1.1
unnamed: C2.1, IC2.7 (CRYSTAL1), Y1.2
unnamed: JP1.2, R10.1, R11.2
unnamed: IC1.14 (VBAT), R17.2
NIRQ: IC2.1 (DIGITAL_3(PWM)), U$7.NIRQ
RESET: IC1.4 (/RST), IC2.29 (RESET), ISP.5, R3.2, RESET.BOT-2
SCK: IC2.17 (DIGITAL_13), ISP.3, U1.5 (SCK), U$7.SCLK
SCL: CN1.D+, IC1.16 (SCL), IC2.28 (ANALOG_5), R15.1
SD-SELECT: IC2.14 (DIGITAL_10(PWM)), U1.2 (CS)
SDA: CN1.D-, IC1.15 (SDA), IC2.27 (ANALOG_4), R16.1
SQW: IC1.3 (SQW/INT), R13.2
SW: CN1.ID, IC2.32 (DIGITAL_2)
VBAT: -BAT+.2 (1), CN1.VBUS, R17.1, SWITCH.2

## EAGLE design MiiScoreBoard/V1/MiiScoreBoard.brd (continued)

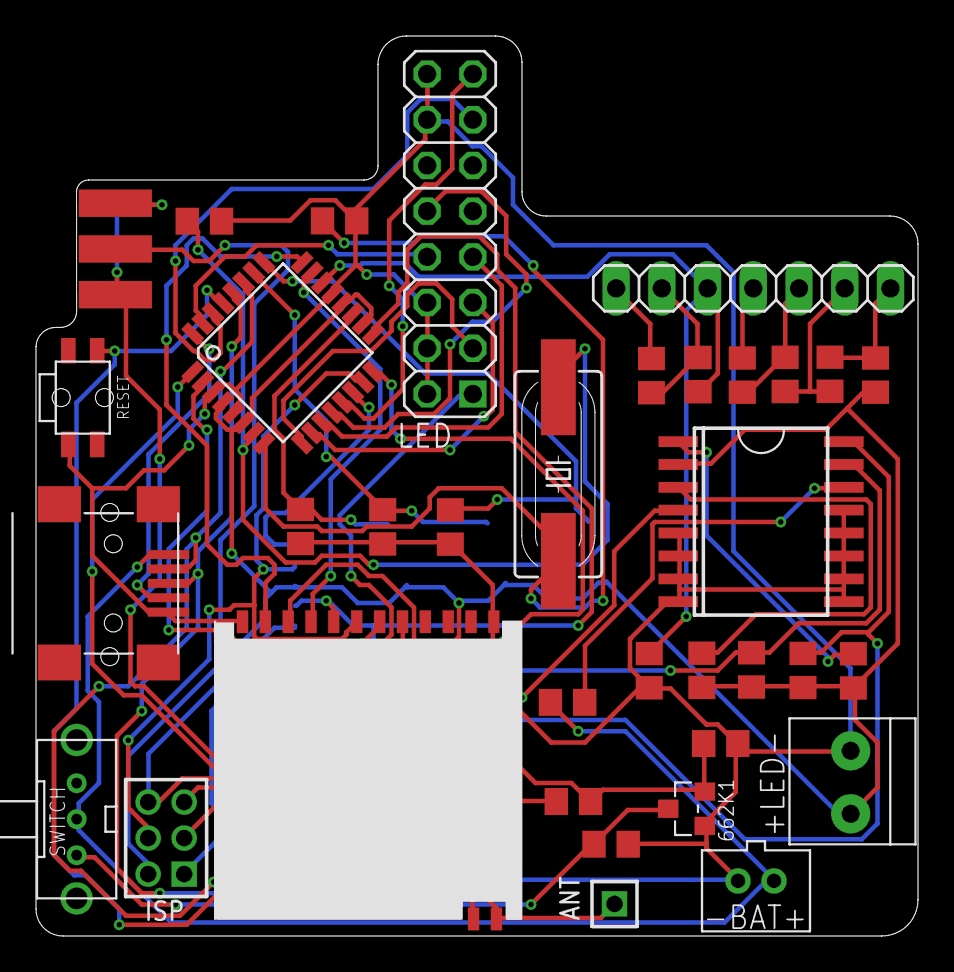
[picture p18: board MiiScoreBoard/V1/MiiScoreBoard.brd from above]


Board: 2 copper layers, 49.0 x 50.0 mm, 40 parts (5 on the bottom side), 40 nets.

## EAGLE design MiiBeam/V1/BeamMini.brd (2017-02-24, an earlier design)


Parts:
C1: 33nF; C0805
C2: 680pF; C0805
C3, C4: 10nF; C0805
C10: 47uF; C0805
CN2: Power; USB-MINIB
CTRL: 1k; TC33X
IC2: 38khz; SO08
IC3: 1.0Khz; SO08
IR: LED5MM
JP2: +BAT-; 1X02M
LED1: LUXEON-2
LED3: Blue; CHIP-LED0805
R1: 22K; M0805
R2, R11: 10k; M0805
R3: 22k; M0805
R4: 2.2k; M0805
R10: 150; M0805
R15: 10; R0805
SWITCH: A-5104SMALL; A-5104-SMALL
T3: 2222; SOT23

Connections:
CTRL: CTRL.2 (S), R15.2
GND: C1.2, C2.1, C3.2, C4.2, C10.1, CN2.GND, IC2.1 (GND), IC3.1 (GND), JP2.1, LED3.C, T3.2 (E)
unnamed: IC3.7 (DIS), R1.1, R2.2
unnamed: C3.1, IC3.5 (CV)
unnamed: C2.2, IC2.2 (TR), IC2.6 (THR), R3.2
unnamed: IC2.7 (DIS), R3.1, R4.2
unnamed: CN2.D-, IC2.4 (R), IC3.3 (Q)
unnamed: C4.1, IC2.5 (CV)
unnamed: IC2.3 (Q), R10.2
unnamed: JP2.2, SWITCH.2
unnamed: C1.1, IC3.2 (TR), IC3.6 (THR), R2.1
unnamed: CN2.D+, R10.1, T3.1 (B)
unnamed: IR.K (C), LED1.C, R15.1
unnamed: CTRL.3 (E), T3.3 (C)
unnamed: LED3.A, R11.2
unnamed: CN2.VBUS, SWITCH.3 (S)
VCC: C10.2, IC2.8 (V+), IC3.4 (R), IC3.8 (V+), IR.A, LED1.A, R1.2, R4.1, R11.1, SWITCH.1 (O)

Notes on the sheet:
2.2KHz Sq.W.
38KHz mod 2.2KHz



Board: 2 copper layers, 19.0 x 26.2 mm, 22 parts (16 on the bottom side), 17 nets.

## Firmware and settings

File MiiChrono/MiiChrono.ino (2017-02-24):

/* Test Client/sever to test communication between two MiiChronoV3.6 devices
   Validate settings, channel,syncwords Ok
   Validate time sync    Ok
   Validate ack system   Ok
   Validate Yield        Ok
   Validate Bluetooth    Ok
   Validate MiiEye       Ok 
   Validate Battery      Ok
   Validate retry system Ok  
   Validate Collision    Ok
   Validate trimPosition Ok
   Validate parallelMode OK
   Validate swapFinish   Ok
   Validate noFinish     Ok
   Validate autoModem
   
   
TODO:
   if send ack to your self push it on to the stack
   Set power as 1-9 and use mapping for real value
   When restart sometimes the start hangs ?
   Support a way to print end results after the run ended (support remote print)
   
   Remove all bluetooth actions and simplify it. 1 Command to Host(Containing message for RF) and 2 a Command to retrieve status info
   Create box below LCD which could contain 2 beam and 2 devices and if possible 5 legs

   Indicator for Power not correct
   Use GSM to send commands to update properties, master sends to all registered clients and waits for OK --> DEVICEIID CODE
   
   When reading Eprom keep the original baud, so we can init the modem correrctly.
   
CODE
    Make the app in Ionic
    Fix Back in ionic
    Use _intCounter in Eye to validate if we are bouncing the interrupt
    When using Master Finish and device is not used for some time we have to show finish again.  Old Code ?

    
BOARD 4.1
    + Add pullup ok 10k to Switch pin. Allowes to use hall without pullup  
    * Add Meassure point for freq
    * Add Resistor to change freq on detail
    * Add step up, allowing to use one battery
    * Create board for Wifi in slot GSM
    * Create board for Bluetooth in slot GSM
 
    Test Wifi + Long Range sender on Step up 5v from two pack battery
   
DONE:
* Remove livespan: Switch was not accepted because livespan of prevAddress had expired in addTime
* Added Printer support
* StartDelay is now managed by Master and start
* Usage of new mode configuration
* Added noFinish
* Fixed swapFinish
* Fixed Bluetooth modem
* State changes works now on start instead of id
* Eye works for version 3 and 5
* Range limitation for version S4432 20Db still not stable
* Fixed firmware size in config
*/

//Set to address of device if we should configure the device MII_DEV_MASTER +/- x allow compiler to over rule
#define MII_ADDRESS MII_DEV_MASTER
#define MII_ADDRESS MII_DEV_START
//#define MII_ADDRESS MII_DEV_FINISH
//#define MII_ADDRESS MII_DEV_PRINTER

//Disable the buzzer for quite testing
#define MII_DISABLE_BUZZER 0

//Set to 1 if we have Bluetooth
#define MII_BLUETOOTH 1

//Set to 1 if we have a beam or 2 if we a combined gate 3 only beam
#define MII_IR_BEAM 1

//Set the default power level, to maximum level
#define MII_TXPOW MII_TXPOW_23DBM

//Default a device has now clock
#define MII_CLOCK 0

//Default a device is not connected to printer, but if set to 1 it will connect to the printer
#define MII_PRINTER 0

//Default a device is not connected to a ESP device
#define MII_ESP 0

#include <Arduino.h>
#include <Time.h>
#include <TimeLib.h>
//Include the libraries
#include <Mii.h>
//Check if we have configured the correct device
#if MII_VERSION<10 || MII_VERSION>=1000
#error Please set the correct MII_VERSION in <Mii.h>
#endif

//Check if we are printer, disable beam and disable bluetooth
#if MII_ADDRESS == MII_DEV_PRINTER
#define MII_PRINTER 1
#define MII_IR_BEAM 0
#endif

#if MII_PRINTER
#include <MiiPrinter.h>
#define MII_BLUETOOTH 0
#endif


#include <MiiConfig.h>
#include <MiiFunctions.h>
#include <OnOff.h>
#include <SPI.h>
#include <MiiGenericModem.h>
#if MII_MODEM == 95
  #include <MiiRF95Modem.h>
#elif MII_MODEM == 22
  #include <MiiRF22Modem.h>
#elif  MII_MODEM == 1
  #include <MiiRFClass.h>
#else  
 #error Please specify MII_MODEM
#endif
#include <MiiRFDevice.h>

#if MII_BLUETOOTH
#include <MiiBluetooth.h>
#else
  #define LOG_DEBUG(str)
  #define LOG_INFO(str)
  #define LOG_WARN(str)
  #define LOG_FAIL(str)
  #define LOG_DEBUG_T(time,str)
  #define LOG_INFO_T(time,str)
  #define LOG_WARN_T(time,str)
  #define LOG_FAIL_T(time,str)
  #define LOG_DEBUG_T2(time,str,str2)
  #define LOG_INFO_T2(time,str,str2)
  #define LOG_WARN_T2(time,str,str2)
  #define LOG_FAIL_T2(time,str,str2)
#endif
#include <EEPROM.h>            //The Basic EEPRom lib
#include <EEPROMAnything.h>    //Read write blocks from eeprom 

//Disable clock does not work it makes SDA behavior strange (HIGH)
#if MII_CLOCK
#include <DS3232RTC.h>            
#include <Wire.h>
#endif

#if MII_ESP
#include <MiiESPCom.h>
MiiEspCom Esp(Serial);
#endif

uint8_t buf[MII_RF_MESSAGE_LEN];

#if MII_PRINTER
class MiiLocalPrinter : public MiiPrinter { public: 
   MiiLocalPrinter() : MiiPrinter(Serial) {}
   void onConnected(){
    MiiPrinter::onConnected();
    doOnOff(&setLed,LED_BLUE,175,175,3); //Bluetooth Connect
    print(F("Connected:"));print(MiiConfig.group%1000);print('.');print(MiiConfig.channel);print('.');println(MiiConfig.address);
    if (year()>2000)  { print(F("Date:"));date(now());println(); }
    print(F("Device "));print(F("Switch"));tab(17);print(F("Nr   "));println(F("Time"));
    line(30);
   }

   void onError(){
    MiiPrinter::onError();
    doOnOff(&setLed,LED_RED,175,175,3); //Bluetooth Connect error   
   }
};
MiiLocalPrinter Printer;
#endif


#ifdef MII_PIN_GATE
 void setGate(uint8_t state){
  digitalWrite(MII_PIN_GATE,state);
}
#endif

//Overwrite some Device function so we can work the ligth and keep track of last msg 
class MiiRFHost : public MiiRFDevice { public:
 MiiRFHost(uint8_t selectPin, uint8_t intPin, uint8_t sdnPin)
  : MiiRFDevice(selectPin,intPin,sdnPin) {
  }

  #if MII_CLOCK
   bool setSessionDate(uint32_t date){
    bool ret =  MiiRFDevice::setSessionDate(date);
    if (ret) {
      uint32_t t = date-(time()/1000);
      RTC.set(t); 
      setTime(t);
    }
   }
  #endif

  bool syncTime(uint8_t address=MII_BROADCAST_ADDRESS){
     doOnOff(&setLed,LED_RED,175); //Failed hart beat client
     return MiiRFDevice::syncTime(address);
  }
  
  //Called when the system time has been changed
  void timingChanged(){
    if (isMaster()){
      doOnOff(&setLed,closestAddress() ? LED_HEART : LED_RED,250); //Flash red if no clients
    } else {
      doOnOff(&setLed,time() ? LED_HEART : LED_RED,250); //Flash red if no time sync
    }
    _lastTiming=millis();
    //On changed data on master side short next hardbeat 
    if (isMaster() && _isChanged) {
       _lastTiming=millis() - (MII_HEARTBEAT_INTERVAL/2);
    } else  _lastTiming=millis();  
    MiiRFDevice::timingChanged();
    #if MII_BLUETOOTH
      Bluetooth.send(time(),MII_CMD_DATA,(uint8_t*)&timing,sizeof(timing_t));
    #endif
    LOG_DEBUG(F("Timing Changed"));
   #if MII_PRINTER
    if (Printer.isConnected()){ 
      //Check if session date has changes, if so change the internal time
      if (timing.sessionDate && timing.sessionDate!=ntiming.sessionDate) {
        setTime(timing.sessionDate+time());
      }
      //Now Check if data has changed
      if (timing.times[0].start+1000<ntiming.times[0].start) { //New start time, clear the data
        Printer.println("Restart Timing");
      } 
      for (int i=0;i<MAX_TIMES;i++){
        int j=0;
        if (timing.times[i].start>ntiming.times[0].start){ //We have a new data
          //We need to keep track of closed starts
          Printer.print(F("Start"));
          Printer.tab(8);
          Printer.print(timing.times[i].start);
          Printer.tab(17);
          Printer.println(timing.times[i].user);
          if (timing.times[i].state>=MII_STATE_FINISH){
            j=MAX_TIMES;
            goto printFinish;
          }
        } else {
           for (j=0;j<MAX_TIMES;j++){
             //We see same time as start and user equal
            if (timing.times[i].start==ntiming.times[j].start &&
             timing.times[i].user!=ntiming.times[j].user){ //user  has changed
              Printer.print(F("Change User "));
              Printer.print(ntiming.times[i].user);
              Printer.print(F(" to "));
              Printer.println(timing.times[i].user);
            }
           //We see same time as start and user equal
           if (timing.times[i].start==ntiming.times[j].start &&
             (timing.times[i].time!=ntiming.times[j].time ||
             timing.times[i].state!=ntiming.times[j].state)
            ){ //Time or state has changed
 printFinish:
              if (timing.times[i].state<MII_STATE_DNF) {
                Printer.print(                   
                   timing.times[i].state==0 ? F("Reopen") :
                   timing.times[i].state<MII_STATE_FINISH ? F("Inter") :
                   timing.times[i].state==MII_STATE_FINISH ? F("Finish") :
                   timing.times[i].state==MII_STATE_FINISH_PREV ? F("Fin L") : F("Fin R") );
                if (timing.times[i].state!=MII_STATE_FINISH_PREV && timing.times[i].state!=MII_STATE_FINISH_LAST) {   
                  Printer.tab(8);
                  Printer.print(timing.times[i].start+timing.times[i].time);
                }
                Printer.tab(17);
                Printer.print(timing.times[i].user);
                if (timing.times[i].state!=0) {
                  if (timing.times[i].state==MII_STATE_FINISH_PREV || timing.times[i].state==MII_STATE_FINISH_LAST) {
                    Printer.tab(22);
                    Printer.print('+');
                    Printer.time(timing.times[i].time,false);
                  } else {
                    Printer.tab(23);
                    Printer.time(timing.times[i].time);
                  }
                }
                Printer.println();
              } else { //State >=DNF
                Printer.print(F("Manual"));
                Printer.tab(17);
                Printer.print(timing.times[i].user);
                Printer.tab(23);
                Printer.println(timing.times[i].state==MII_STATE_DNF ? F("DNF") :
                   timing.times[i].state<=MII_STATE_DSQ_R ? F("DSQ") :
                   timing.times[i].state<=MII_STATE_DNS_R ? F("DNS") :
                   timing.times[i].state==MII_STATE_REMOVED ? F("DEL") :
                   F("INV"));           
              }
            }
         }
        }
      }
    }
    ntiming=timing;
   #endif
  }
 
  #if MII_PRINTER
  switchRec_t switches[MII_MAX_GATES];
  timing_t ntiming; //Last processed timing
  //Catch the swith Command
  void logSwitch(uint8_t id,uint32_t time){
    if (!Printer.isConnected()) return;   
    uint8_t i=0;
    for (;i<MII_MAX_GATES && switches[i].id!=0;i++){
       if (id==switches[i].id) {
          goto updateSwitch;
        }
    }
    if (i<MII_MAX_GATES && switches[i].id==0) { //We need to add
 updateSwitch:       
        if (time!=switches[i].time) {
          //Just Print the switch
          Printer.print(id);
          Printer.tab(8);
          Printer.println(time);    
          //Store the switch time so we don't print double times
          switches[i].time=time;
          switches[i].id=id;
        }
      }
  }
  
  void afterSend(const uint8_t* data=0, uint8_t len=0){
    if (_txHeaderId==MII_CMD_SWITCH) {
       logSwitch(_txHeaderFrom,*(uint32_t*)data);
    }
    MiiRFDevice::afterSend();
  }
  #endif

   #if MII_ESP || MII_PRINTER
   bool beforeProcess(){ 
   #if MII_ESP
     uint8_t len; 
     len=MII_SIZEOF_timing_t;
     recv((uint8_t*) &smallbuf[0],&len,true);
     Esp.send((uint8_t)_rxHeaderId,(uint8_t*)&smallbuf[0],len);
   #endif
   #if MII_PRINTER
   if (_rxHeaderId==MII_CMD_SWITCH) {    
        uint32_t time;
        uint8_t len=sizeof(uint32_t);
        if (recv((uint8_t*) &time,&len,true)) {
          logSwitch(_rxHeaderFrom,time);  
        }
    }
    #endif
    return MiiRFDevice::beforeProcess();
  }
  #endif

    //Pull up the GATE pin if defined
  #ifdef MII_PIN_GATE
  void countdownGo(){
   setGate(LOW);
   doOnOff(&setGate,HIGH,5000); //Set the gate high after 5 seconds
  }
  #endif
     
  //Called by main loop, todo some processing   
  void doProcess(){
     #if MII_ESP
      if (Esp.available()) {
        if (Esp.isAction()){
          uint8_t len= MII_SIZEOF_timing_t;
          Esp.read((uint8_t*)smallbuf,len);
          Esp.send(sendAckCmd(Esp.getCmd(),(uint8_t*)smallbuf,len) ? MII_ESP_CMD_OK : MII_ESP_CMD_FAIL,0,0,false);
        } else Esp.clear();
      }
    #endif
    if (isMaster() && _lastTiming+MII_HEARTBEAT_INTERVAL<millis()) {
         if (!sendTiming()) {
            doOnOff(&setLed,LED_RED,175); //Failed hart beat
         }
    }
    if (!isMaster() && (_lastTiming+(MII_HEARTBEAT_INTERVAL*4))<millis()){
      _lastTiming=millis();
       doOnOff(&setLed,LED_RED,175); //Failed hart beat client
    } 
  }
  
  uint32_t _lastTiming;
   
};

//Init the classes we will use
MiiRFHost rf(MII_PIN_RF_CS,MII_PIN_RF_IRQ,MII_PIN_RF_SDN);

#if MII_IR_BEAM
#include <MiiEye.h>
 #if MII_IR_BEAM == 3
  MiiEye eye(MII_PIN_EYE_CS,MII_PIN_EYE_IRQ);
 #elif MII_IR_BEAM == 2
  MiiEye eye(MII_PIN_EYE_CS,MII_PIN_EYE_IRQ,MII_PIN_EYE_T1,MII_PIN_EYE_T2);
 #else
  MiiEye eye(MII_PIN_EYE_CS,MII_PIN_EYE_IRQ,MII_PIN_EYE_T1);
 #endif 
#endif


//Setup all ports and init all classes and variables
void setup() {  
  
  //Init led Pins
  pinMode(MII_PIN_LED_RED,OUTPUT);
  pinMode(MII_PIN_LED_GREEN,OUTPUT);
  pinMode(MII_PIN_LED_BLUE,OUTPUT);
  setLed(LED_OFF);
  
  //Init pin for Buzzer and make sure it is off
  pinMode(MII_PIN_BUZZER,OUTPUT);
  setBuzzer(LOW);
  #if MII_DISABLE_BUZZER 
    pinMode(MII_PIN_BUZZER,INPUT); //Disable buzzer by making pin input
  #endif
  
  #if MII_CLOCK
    //RTC.set(1431961440L);
    setSyncProvider(RTC.get);   // the function to get the time from the RTC
  #endif
  
  //Battery Check
  uint8_t battery = getBatteryLevel();
  setLed(battery<=BATTERY_LOW ? LED_RED : (battery<=BATTERY_MEDIUM ? LED_BLUE : LED_GREEN));

  if (readConfig(MII_DEVICE_ID,MII_ADDRESS,MII_TXPOW,MII_FIRMWARE)){
    //Whe have read new config file  
    #if MII_BLUETOOTH
      Bluetooth.begin(MII_DEVICE_ID,MII_ADDRESS);
    #endif  
    LOG_INFO(F("Config EEPROM"));
  } else {  
   #if MII_BLUETOOTH
     Bluetooth.begin();
     LOG_INFO(F("Normal Start"));
   #endif
  }
  //Keep the battery led on for at least 1 seconds + modem startup
  delay(1000);
    
  //We set the mode
  uint8_t mode = MII_MODE_TIME;
  
  /* We have disable this code, we should only use one of them as control function
   #if MII_VERSION >= 38
     uint8_t pos;
     //Group pin will control channel and group so you can link devices from diffrent types 
     if (pos=trimPosition(MII_PIN_GROUP)) { 
        MiiConfig.group=pos*MAX_POSITIONS;
        MiiConfig.channel=pos*3;
     } 
     if (pos=trimPosition(MII_PIN_FREQ))  { //Set powerlevel instead of freq
          MiiConfig.power=map(pos,1,MAX_POSITIONS,MII_TXPOW_1DBM,MII_TXPOW_20DBM);
     }
     //Check if we should change the id, or even go to parrallel mode
     if (pos=trimPosition(MII_PIN_ID)) {
         if (pos>12){ //MAX ID WHE CAN SET 240
           MiiConfig.address=MII_DEV_MASTER;
           mode = MII_MODE_PARALLEL;
         } else MiiConfig.address=pos*20;
     }
  #endif
  */  
   
   if (!rf.init(MiiConfig.address,MiiConfig.group,MiiConfig.channel,MiiConfig.power,MiiConfig.address==MII_DEV_MASTER)) {
 
    LOG_WARN(F("Failed RF"));
    doOnOff(&setLed,LED_RED,175,175,100);
    delay(5000);
    RESTART();
  }
  rf.setMode(mode);
  
  
  #if MII_CLOCK
    if (rf.isMaster()){
      rf.setSessionDate(now());
    }
  #endif
  
  #if MII_BLUETOOTH >= 2
      sprintf((char*)buf,"Device: %d.%d.%d %d",MiiConfig.group%1000,MiiConfig.channel,MiiConfig.address,mode);
      Bluetooth.log(0,3,(char*)buf);
  #endif 
 
  setLed(LED_OFF);
    
  #if MII_IR_BEAM
    if (!eye.init(false)) {
      LOG_WARN(F("Failed EYE"));
      RESTART();
    } 

   if (eye.isExternal()) {LOG_WARN(F("EXTERNAL EYE"));}
  #endif

  #if MII_PRINTER
    Serial.begin(MII_PRINTER_BAUD);
    Printer.begin("MSP-100",1234);
  #endif

  #if MII_ESP
    Esp.begin();
  #endif

  //Pull up the GATE pin if defined
  #ifdef MII_PIN_GATE
   pinMode(MII_PIN_GATE,OUTPUT);
   setGate(HIGH);
  #endif
}


//In the RF Library yield is called when we are in waiting loops. 
//Make sure we call validate so we don't miss a event
void yield(){
  #if MII_IR_BEAM
  if (MiiConfig.address < MII_DEV_CLIENT && eye.isReady()){ //Only run this process when eye is ready.
    eye.validate(); //Ensure the eye is validate during idle time
    //Check if the beam is armed
    if (!eye.isExternal() && !eye.isArmed()) { //If we are not external and not arm show it
        if (eye.isActive()){
          doOnOff(&setLed,LED_GREEN,1000);
          if (MiiConfig.armSound) delOnOff(&setBuzzer); //Sound off so we can aim beam
        } else {
          doOnOff(&setLed,LED_RED,1000);
          if (MiiConfig.armSound) doOnOff(&setBuzzer,HIGH,1000); //Sound beep short so we can aim beam
        }
    } 
  }
  #endif
  processOnOff(); //Run the background process for OnOff
}

void loop(){
  //Check the IR beam
  #if MII_IR_BEAM
   if (MiiConfig.address < MII_DEV_CLIENT ) {
    uint32_t irTime=eye.getTime();
    if (irTime!=0) {
     bool ack=false; 
     doOnOff(&setLed,LED_SWITCH,425); //First long flash
     if (rf.addTime(rf.time(irTime),MiiConfig.address)) {
       doOnOff(&setLed,LED_SWITCH,350); //Long flash when accepted       
       doOnOff(&setBuzzer,HIGH,350);
       LOG_INFO(F("SWITCH TRG OK"));
     } else {
       doOnOff(&setLed,LED_RED,350); //We failed the switch
       LOG_FAIL(F("SWITCH TRG FAILED"));
     }
   } 
  }  
  #endif
  
  //Process any rf data
  if (rf.available()){
    uint8_t len=sizeof(buf);
    bool read=false;
    switch (rf.headerId()){
      #if MII_BLUETOOTH
      case MII_CMD_LOG: {
        if (read=rf.recv(buf,&len)) {
          buf[len]='\0';
          Bluetooth.log(0,(char*)buf);
        }   
      } break;
      #endif
      
     case MII_CMD_GET_CONFIG: {
       if (rf.headerTo()!=MII_BROADCAST_ADDRESS)
          rf.sendCmd(MII_CMD_SET_CONFIG,(uint8_t*)&MiiConfig,sizeof(miiConfig_t),rf.headerFrom());
      } break;
   
    } //End Of Switch
    //Check if we should remove the data
    if (!read) rf.recv();
  } 
  
  
  //Do the bluetooth processing
  #if MII_BLUETOOTH > 0
     uint8_t c = Bluetooth.available();
     switch (c) {
       case 0: break; //No command
        case MII_CMD_SERIALID: { //Return the serial id and our firmware version
         Bluetooth.send(rf.time(),MII_CMD_SERIALID,(uint8_t*)&MiiConfig.id,sizeof(uint32_t)); 
         //SerialId request will also send FIRMWARE back to Device
        }
        
       case MII_CMD_FIRMWARE: {  
         Bluetooth.send(rf.time(),MII_CMD_FIRMWARE,(uint8_t*)&MiiConfig.firmware,sizeof(uint16_t));
        }break;
      
       case MII_CMD_SET_MODE:{ 
          uint8_t mode;
          if (Bluetooth.read(&mode,sizeof(mode))) rf.setMode(mode);
        }break;
     
       case MII_CMD_CLEAR: {
          if (rf.isMaster()) rf.clearData();
          else rf.sendAckCmd(MII_CMD_CLEAR,(uint8_t*)NULL,0);
       }break;

       case MII_CMD_NO_FINISH : {
        rf.noFinish();
       } break;
       case MII_CMD_SWAP_FINISH : {
         rf.swapFinish();
       }break;
    
        case MII_CMD_SET_DATE: {
          uint32_t date;
          //Correct the date (in sec) only if allready running
          if (rf.time() && Bluetooth.read((uint8_t*)&date,sizeof(date))) 
            rf.setSessionDate(date);
        }break;  
   /* //Parts not used comment out save space    
       case MII_CMD_GET_CONFIG: {
         Bluetooth.send(rf.time(),MII_CMD_SET_CONFIG,(uint8_t*)&MiiConfig,sizeof(miiConfig_t));
       }break;  
       
       case MII_CMD_SET_CONFIG: { //Set the config
         if (Bluetooth.read((uint8_t*)buf,sizeof(miiConfig_t))) {
           writeConfig((miiConfig_ptr)buf,7); //Dont write id(4),firmware(2),address(1)
           RESTART();
         }
       }break;
*/
/*
      case MII_CMD_SET_BOUNDARY: {
         if (Bluetooth.read((uint8_t*)buf,sizeof(boundaryRec_t))) 
          rf.setBoundary(((boundaryRec_ptr)buf)->minBoundary,((boundaryRec_ptr)buf)->maxBoundary);
       }break;
       
       case MII_CMD_SET_DELAY:{ 
          uint32_t startDelay;
          if (Bluetooth.read((uint8_t*)&startDelay,sizeof(startDelay))) rf.setStartDelay(startDelay);
       }break;
   */    
       case MII_CMD_SET_STATE: {
         if (Bluetooth.read((uint8_t*)buf,sizeof(stateRec_t))) { 
          rf.setState(*(stateRec_ptr)buf);
         }
       }break;

       case MII_CMD_SET_USER: {
          uint16_t nextUser;
          if (Bluetooth.read((uint8_t*)&nextUser,sizeof(nextUser))) {
            rf.setNextUserId(nextUser);
          }
        }break;
        
        case MII_CMD_SET_SESSION: {
          uint16_t session; 
          if (Bluetooth.read((uint8_t*)&session,sizeof(session))) 
              rf.setSession(session);
          }break;
          
         default: {
          LOG_DEBUG(F("UNKNOWN CMD"));
         }break; 
         
     }
     //Clear the command
     Bluetooth.clear(); 
  #endif
  
  //Do the processing of the rf
  rf.doProcess();
  
  //Do the printer processing
  #if MII_PRINTER
    Printer.doProcess();
  #endif

  
  //Do the pocessing of the on off switching and beam checking
  yield();
}

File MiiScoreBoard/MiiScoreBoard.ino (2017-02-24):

/* TODO
As of version 2.1 we should 
-support printer
-ESP-01
-EEpprom to store data

Parallel mode 
0. Aansluitingen over GSM pins
1. Start (keyboard (CTRL) or External Command) count down over buzzer and external speaker (BRX)
2. On start down unlock the gates and start clock

If key on analog use digtal read instead of analog.
on beam add audio plug as charger

*/

//The Reduction of the ID
#define MII_DEV 0
 
//Default a device is not connected to printer, but if set to 1 it will connect to the printer
#define MII_PRINTER 0

//Enable or disable ESP
#define MII_ESP 0

//Do we have the internal clock enabled
#define MII_CLOCK 0

//Include the libraries
#include <Mii.h>
//Check if we have configured the correct device
#if MII_VERSION<1000 || MII_VERSION>=2000
#error Please set the correct MII_VERSION in <Mii.h>
#endif

#include <MiiConfig.h>
#include <MiiFunctions.h>
#include <SPI.h>
#include <MiiGenericModem.h>
#if MII_MODEM == 95
  #include <MiiRF95Modem.h>
#elif MII_MODEM == 22
  #include <MiiRF22Modem.h>
#elif  MII_MODEM == 1
  #include <MiiRFClass.h>
#else  
 #error Please specify MII_MODEM
#endif
#include <MiiRFClient.h>
#include <LEDMatrix.h>
#include <EEPROM.h>            //The Basic EEPRom lib
#include <EEPROMAnything.h>    //Read write blocks from eeprom 
#include <Time.h>
#include <TimeLib.h>
#if MII_CLOCK
#include <DS3232RTC.h>         
#include <Wire.h>        
#endif

#if MII_ESP
#include <MiiESPCom.h>
MiiEspCom Esp(Serial);
#endif


//Default powerlevel must be after Mii.h
#define MII_POWER MII_TXPOW_17DBM
//Width and Height of display
#define WIDTH   64
#define HEIGHT  16
//We wait for 8.5 seconds before returning to next time
#define FREEZE_DELAY 8500
//We refresh display every .5 sec
#define REFRESH 500
//Time in ms when clock returns to time (3 min)
#define RELEASE_TIME 180000L

// Display Buffer 128 = 64 * 16 / 8
uint8_t displaybuf[WIDTH *HEIGHT / 8];
uint8_t drawbuf[WIDTH *HEIGHT / 8];
//Small buffer used for intermediate stuff like date
char smallbuf[MII_SIZEOF_timing_t];

// LEDMatrix    (a, b, c, d, oe, r1, stb, clk);
LEDMatrix lcd(MII_PIN_LCD_A,MII_PIN_LCD_B, MII_PIN_LCD_C, MII_PIN_LCD_D, MII_PIN_LCD_OE, 
              MII_PIN_LCD_R1, MII_PIN_LCD_LT, MII_PIN_LCD_CLK );

#if MII_PRINTER
#include <MiiPrinter.h>
#include <SoftwareSerial.h>
//SoftwareSerial sSerial(MII_PIN_BRX ,MII_PIN_BTX); 
SoftwareSerial sSerial(1,2); //Temp fix for version 2.1 (A7,2)
class MiiLocalPrinter : public MiiPrinter { public: 
   MiiLocalPrinter() : MiiPrinter(sSerial) {}
   void onConnected(){
    MiiPrinter::onConnected();
    print(F("Connected:"));print(MiiConfig.group%1000);print('.');print(MiiConfig.channel);print('.');println(MiiConfig.address);
    if (year()>2000)  { print(F("Date:"));date(now());println(); }
    print(F("Device "));print(F("Switch"));tab(17);print(F("Nr   "));println(F("Time"));
    line(30);
   }
   void onError(){
  _step=0; //Failure
   }

   void doProcess() {
  if (_step>=BT_READY) return;
  if (_wait>millis() && _step!=17) {
    return; //We still need to wait before we can process next command
  }
  int cmd=0;

  switch (_step) {
     case 0 :
    // serial.println(F("AT"));
      serial.println(F("AT"));
      goto processWaitExit;
/*
     case  0 :
       serial.println(F("AT+DISC"));  //Disconnect, can throw error
       goto processWaitExit;
     case 1:
       clearBuf(); ///Ignore error of not connected
       _step++;
       break;
*/
     case 2 :
      serial.println(F("AT+RMAAD"));  //will release the module from any previous PAIR.
      goto processWaitExit;
     case 4 :
      serial.println(F("AT+ROLE=1"));  //Set mode to Master
      goto processWaitExit;
     case 6 :
      serial.println(F("AT+RESET"));  //After changing role, reset is required
      goto processWaitExit;
     case 8:
      serial.println(F("AT+CMODE=1"));  //Allow connection to any address
      goto processWaitExit;
     case  10:
      serial.print(F("AT+INQM=0,")); serial.print(BT_SEARCH_COUNT);serial.print(',');serial.println(BT_SEARCH_TIME);  //Inquire mode - Standard, stop after 5 devices found or after 5 seconds
      goto processWaitExit;
     case  12:
      serial.print(F("AT+PSWD="));serial.println(_pinCode);  //Set the pinCode
      goto processWaitExit;
     case  14 :
      serial.println(F("AT+INIT"));  //Start serial Port Profile (SPP) ( If Error(17) returned - ignore as profile already loaded)
      goto processWaitExit;
     case 15  :
       clearBuf(); ///Ignore error of 14
       _step++;
       break;

     case 16 :
       clearBuf();
       serial.println(F("AT+INQ"));  //Start searching for devices, we will fall through to 17
       _step++;
       _wait=millis()+(BT_SEARCH_TIME+5)*1000; //We will wait the search time and 5 second before erroring out
       _listPos=0;
       break;

     case 17 :
       if (_wait<millis()) {
        if (_listPos>0) { //Should not happend but just to be sure.
          _step++;
        } else {
           onError(); //OOPS We timed out, go back to begining
        }
       } else {
         while (serial.available()) {
           cmd=serial.read();
           //Fill the address table--> +INQ:2:72:D2224,3E0104,FFBC <part1>:<part2>:<part3> , type, signal
           if (cmd=='+') {
              //SKIP INQ:
              uint8_t pos = 4;
              while (pos>0) { if (serial.available()) {cmd=serial.read();pos--;}}
              pos=0;
              while (pos<sizeof(btaddress_t) && cmd!=','){
                if (serial.available()) {
                  cmd=serial.read();
                  _list[_listPos].address[pos++]=cmd==',' ? '\0' : cmd==':' ? ',' : cmd;
                }
              }
              _listPos++;
              //Remove till end of line
              while (serial.read()!='\r'){}
           } else if (cmd=='O') {
             while (!serial.available() &&  _wait<millis()){}
             if (serial.read()=='K') {
              clearBuf();
              _step++;
              return;
             }
           }
         }
       }
       break;

     case 18:
      //We found a bluetooth device and stored them in the list
      //Now loop and query name for each found device and see if we have match
      clearBuf();
      if  (_listPos>0) {
        _listPos--;
        serial.print(F("AT+RNAME?"));serial.println(_list[_listPos].address);
        _wait=millis()+4000;
        _step++;
      } else {
        _step=16; //No Data search again
      }
      break;
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

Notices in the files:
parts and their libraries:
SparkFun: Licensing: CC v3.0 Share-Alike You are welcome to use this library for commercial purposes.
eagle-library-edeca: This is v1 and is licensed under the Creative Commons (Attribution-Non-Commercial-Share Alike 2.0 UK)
